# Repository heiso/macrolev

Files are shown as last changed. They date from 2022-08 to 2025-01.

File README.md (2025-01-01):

<div align="center" >
  Macrolev - Open Source Analog Keyboard
  <br>
  <br>
  <br>
  <div>
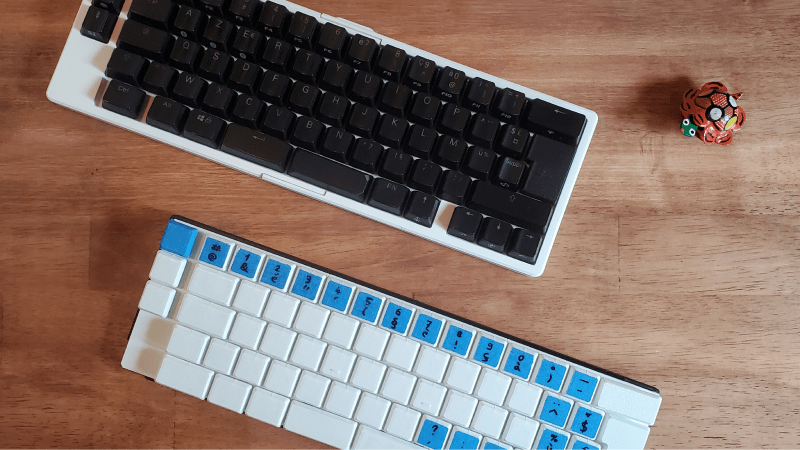
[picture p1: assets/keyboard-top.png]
keyboard - picture from above
    
  </div>
  <span>
    <a href="assets/keyboard-bot.png">bottom picture</a> - <a href="assets/pcb-bot.png">pcb picture</a> - 
  </span>
  <br>
  <br>
</div>

# Macrolev - Open Source Analog Keyboard

I use the two prototypes shown above as my daily drivers for both coding and gaming. They work well, and the current state of the web configurator is sufficient for seamlessly switching between coding and gaming modes. The current layout of my prototypes is Mac ISO azerty (FR).

## Features

- **Analog Input:** Each key detects varying levels of pressure thanks to Hall Effect technology, allowing for a more responsive and sensitive typing experience.
- **Rapid Trigger Support:** Enables keys to actuate without fully releasing, allowing for faster response times during intense usage (e.g., gaming or rapid typing).
- **Continuous Rapid Trigger:** For keys that require repeated pressing (e.g., in gaming), this feature allows automatic repeated key input with a single press.
- **Tap and Hold Functionality:** Each key can be assigned two functions. A tap function for quick presses and a hold function for longer presses. This is ideal for combining shortcuts or creating multi-functional keys, such as assigning the right Shift key to act as an arrow up when tapped.
- **Web-Based Configurator:** Allows customization of key sensitivity and rapid trigger settings, with future updates planned to enable key mapping and expanded functionality. (see [screenshot](assets/web-configurator-screenshot.png))

## Todos

This is still a work in progress, the firt revision is working flawlessly but it is not that configurable yet. Here is some of the things I'm working on right now

- [x] PCB Rev 2.0
- [ ] Explore other MCUs
  - [ ] esp32-s3 (in progress)
  - [ ] nRF52840
  - [ ] RP2354 ?
- [ ] Add Bluetooth
- [ ] Configure layout and key mapping from the web interface
- [ ] Improve performances

## Links

- [keyboard layout](http://www.keyboard-layout-editor.com/#/gists/9dc992fd631d9f29cc5bdf738b10b4e4)
- [Onshape - Case](https://cad.onshape.com/documents/2af2025c576c4f084cb26625/w/9564bb1d9dfbd4b4af4294c8/e/e2406b8294380372b9116245)
- [Onshape - Low profile MX keycaps](https://cad.onshape.com/documents/93ff700fd3fbb6e9cde6f6e3)
- [Rev 1.0 Schema](https://kicanvas.org/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)
- [Rev 1.0 Pcb](https://kicanvas.org/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)
- [Rev 2.0 Schema](https://kicanvas.org/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)
- [Rev 2.0 Pcb](https://kicanvas.org/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)
- [Rev 2.0 Schema (daughter board)](https://kicanvas.org/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)
- [Rev 2.0 Pcb (daughter board)](https://kicanvas.org/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)
- [Web Configurator](https://heiso.github.io/macrolev/)

## Misc

### References

- ~~[RP2040 Datasheet](https://datasheets.raspberrypi.com/rp2040/rp2040-datasheet.pdf)~~
- ~~[RP2040 Hardware Design](https://datasheets.raspberrypi.com/rp2040/hardware-design-with-rp2040.pdf)~~
- ~~[kb2040 doc](https://learn.adafruit.com/adafruit-kb2040/downloads)~~
- ~~[RPi Pico Debugger Shoe](https://github.com/ShawnHymel/rpi-pico-debugger-shoe)~~
- [Dilemma keyboard](https://github.com/Bastardkb/Dilemma)
- [0xB2 - splinky](https://github.com/plut0nium/0xB2)
- [Sub Reddit](https://www.reddit.com/r/PrintedCircuitBoard/search/?q=rp2040&restrict_sr=1&sr_nsfw=&include_over_18=1)
- [layout/design ref](https://geekhack.org/index.php?topic=103671.0)
- [cirque trackpad](https://www.cirque.com/glidepoint-circle-trackpads)
- [MagLev_Switch_MX](https://github.com/famichu/MagLev_Switch_MX)
- [Anatomy of a keyboard](https://matt3o.com/anatomy-of-a-keyboard/)
- [Switches/Stabs Kicad footprints from ebastler/marbastlib](https://github.com/ebastler/marbastlib)
- [Reddit Post about someone building a lekker switch based keyboard](https://www.reddit.com/r/PrintedCircuitBoard/comments/152kt63/review_request_analog_hall_effect_75_iso_keyboard/)
- [Riskable projects](https://github.com/riskable)
- [Fluxpad with lekker switches](https://github.com/sssata/fluxpad)
- [STM32F411CEU6 documentation](https://www.st.com/en/microcontrollers-microprocessors/stm32f411ce.html#documentation)
- [Wooting 60HE pcb](https://github.com/heiso/macrolev/tree/main/ref/Wooting-60HE)
- [Connecting to uncommon HID devices](https://developer.chrome.com/articles/hid)
- [HID Descriptor parser](https://eleccelerator.com/usbdescreqparser/)
- [peppapighs HE8 keyboard](https://github.com/peppapighs/HE8)
- [peppapighs libhmk library](https://github.com/peppapighs/libhmk)
- [nuphy configurator demo](https://drive.nuphy.io/?isDemoMode=true)
- [geonworks configurator demo](https://venom.how/)
- [wooting configurator demo](https://wootility.io/)

### Tooling

- [QMK keyboard test](https://config.qmk.fm/#/test)
- [Keyboard ghosting interactive demonstration](https://www.microsoft.com/applied-sciences/projects/anti-ghosting-demo)
- [Kicad lib marbastlib](https://github.com/ebastler/marbastlib)
- [Debug HardFault](https://interrupt.memfault.com/blog/cortex-m-hardfault-debug)
- [ai03 Plate Generator](https://kbplate.ai03.com/)
- [JLC2KiCad_lib](https://github.com/TousstNicolas/JLC2KiCad_lib)

Add footprints and symbols from jlcpcb with this cmd

```bash
JLC2KiCadLib <...LCSC refs> -dir JLCPCB -symbol_lib JLCPCB
```

### PCB reviews

- [Review request on PrintedCircuitBoard (Rev 1.0)](https://www.reddit.com/r/PrintedCircuitBoard/comments/17hjp88/review_request_analog_keyboard)
- [Second review request on PrintedCircuitBoard (Rev 1.0)](https://www.reddit.com/r/PrintedCircuitBoard/comments/17kqc2j/review_request_analog_keyboard_2/)
- [Third review request on PrintedCircuitBoard (Rev 2.0)](https://www.reddit.com/r/PrintedCircuitBoard/comments/1h432q5/review_request_open_source_analog_keyboard/)

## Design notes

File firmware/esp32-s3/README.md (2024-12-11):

## Configure the project

Install idf.py cmd [https://docs.espressif.com/projects/esp-idf/en/latest/esp32/get-started/index.html]

```bash
mkdir ~/esp
cd ~/esp
git clone git@github.com:espressif/esp-idf.git
cd esp-idf
git submodule update --init --recursive
./esp-idf/install.sh
```

Then in your project `. ~/esp/esp-idf/export.sh`

Before project configuration and build, make sure to set the correct chip target using `idf.py set-target TARGET` command.

## Erase the NVRAM

Before flash it to the board, it is recommended to erase NVRAM if user doesn't want to keep the previous examples or other projects stored info 
using `idf.py -p PORT erase-flash`

## Build and Flash

Build the project, flash it to the board, and start the monitor tool to view the serial output by running `idf.py -p PORT flash monitor`.

(To exit the serial monitor, type `Ctrl-T + Ctrl-X`)

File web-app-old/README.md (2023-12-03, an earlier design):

# UwU Stack &middot; 

## Install and first run

```bash
npm i
cp .env.tpl .env
npm run up
npm run reset-database
npm run log
```

Then go to http://localhost:3000

## DevEnv actions

Start

```bash
npm run up
```

Show logs

```bash
npm run log
```

Stop

```bash
npm run down
```

Restart

```bash
npm run restart
```

Truncate Database, Migrate and apply seeds

```bash
npm run reset-database
```

Run Lint

```bash
npm run lint
```

Run tests

```bash
npm run test
```

## TODO

- ✅ ...Done
- ⌛️ ...In Progress
- 🚨 ...Bug
- 🚧 ...Improvment

- full sqlite option
- redis/postgres option
- auth flow
- ui

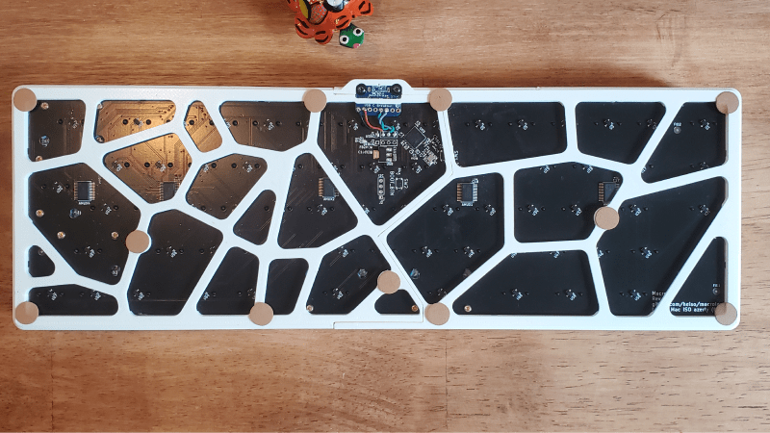
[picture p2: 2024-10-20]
assets/keyboard-bot.png

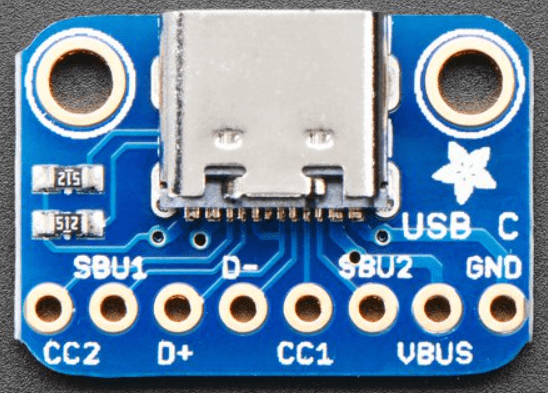
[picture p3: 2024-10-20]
assets/usbc.png

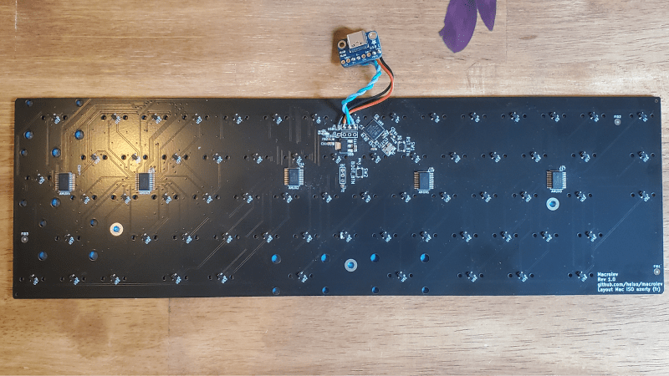
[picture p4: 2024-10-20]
assets/pcb-bot.png

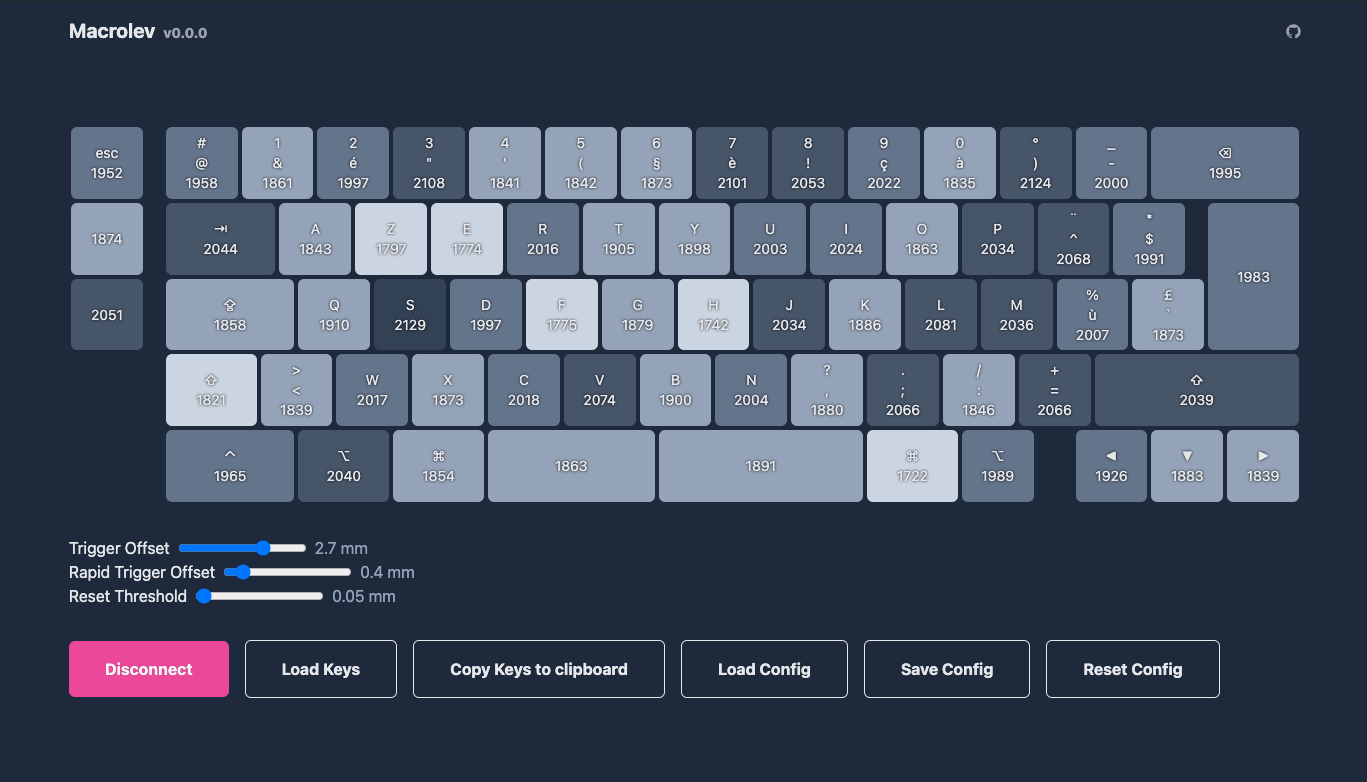
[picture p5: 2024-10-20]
assets/web-configurator-screenshot.png

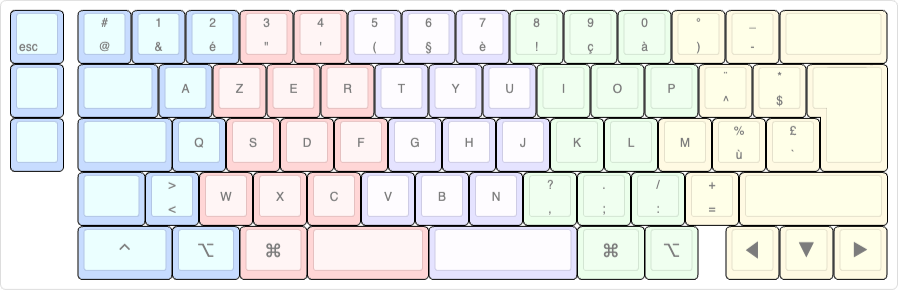
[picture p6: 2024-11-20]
assets/mac-iso-azerty-(fr).png

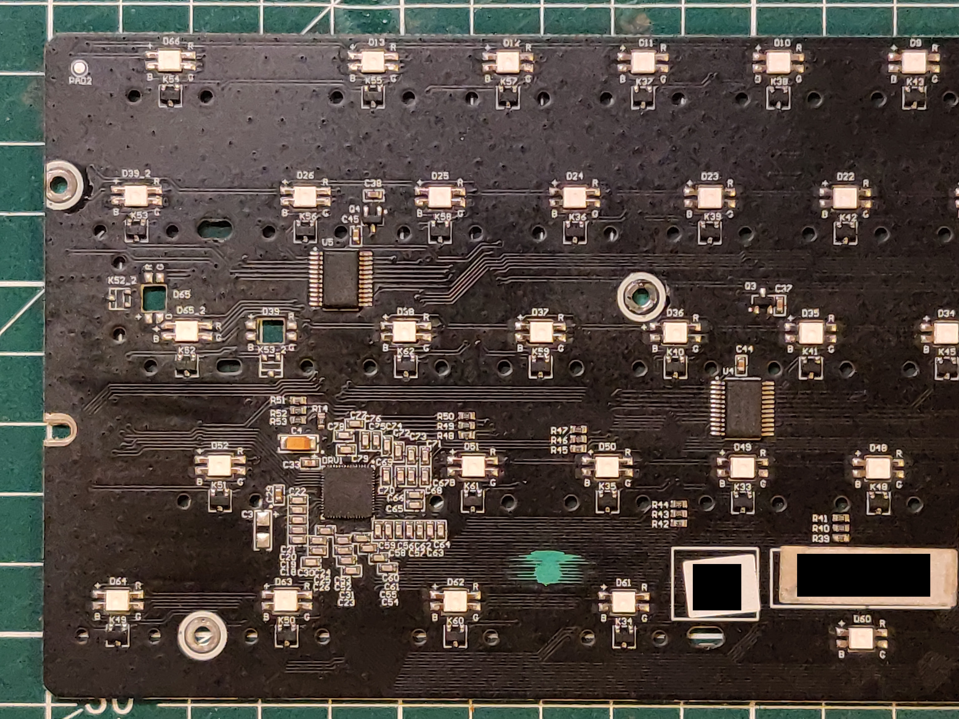
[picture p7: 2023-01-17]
ref/Wooting-60HE/W60HE-15.jpg

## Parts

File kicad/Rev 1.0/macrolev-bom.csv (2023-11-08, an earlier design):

Item | Qty | Reference(s) | Value | LibPart | Footprint | Datasheet | DNP | LCSC
1 | 5 | AMUX0, AMUX1, AMUX2, AMUX3, AMUX4 | CD74HC4067SM | 74xx:CD74HC4067SM | Package_SO:SSOP-24_5.3x8.2mm_P0.65mm | http://www.ti.com/lit/ds/symlink/cd74hc4067.pdf |  | C98457
2 | 1 | C1 | 10u | Device:C | Capacitor_SMD:C_0603_1608Metric_Pad1.08x0.95mm_HandSolder | ~ |  | C19702
3 | 10 | C2, C3, C4, C5, C9, C14, C15, C16, C17, C18 | 100n | Device:C | Capacitor_SMD:C_0402_1005Metric_Pad0.74x0.62mm_HandSolder | ~ |  | C1525
4 | 1 | C6 | 10n | Device:C | Capacitor_SMD:C_0402_1005Metric_Pad0.74x0.62mm_HandSolder | ~ |  | C15195
5 | 2 | C7, C8 | 1u | Device:C | Capacitor_SMD:C_0402_1005Metric_Pad0.74x0.62mm_HandSolder | ~ |  | C52923
6 | 2 | C10, C11 | 22u | Device:C | Capacitor_SMD:C_0805_2012Metric_Pad1.18x1.45mm_HandSolder | ~ |  | C45783
7 | 2 | C12, C13 | 20p | Device:C | Capacitor_SMD:C_0402_1005Metric_Pad0.74x0.62mm_HandSolder | ~ |  | C1554
8 | 1 | D1 | RED | Device:LED | LED_SMD:LED_0603_1608Metric_Pad1.05x0.95mm_HandSolder | ~ |  | C2286
9 | 2 | FB1, FB2 | 120R | Device:FerriteBead | Inductor_SMD:L_0603_1608Metric_Pad1.05x0.95mm_HandSolder | ~ |  | C76892
14 | 2 | R1, R2 | 1.2K | Device:R | Resistor_SMD:R_0402_1005Metric_Pad0.72x0.64mm_HandSolder | ~ |  | C25862
15 | 2 | R3, R4 | 10k | Device:R | Resistor_SMD:R_0402_1005Metric_Pad0.72x0.64mm_HandSolder | ~ |  | C25744
16 | 1 | R5 | 5.1k | Device:R | Resistor_SMD:R_0402_1005Metric_Pad0.72x0.64mm_HandSolder | ~ |  | C25905
17 | 1 | SW1 | RST_BTN | Switch:SW_Push_Dual | switch:SKRPACE010 | ~ |  | C139797
18 | 1 | SW2 | BOOT_BTN | Switch:SW_Push_Dual | switch:SKRPACE010 | ~ |  | C139797
19 | 67 | U1, U2, U3, U4, U5, U6, U7, U8, U9, U10, U11, U12, U13, U14, U15, U16, U17, U18, U19, U20, U21, U22, U23, U24, U25, U26, U27, U28, U29, U30, U31, U32, U33, U34, U35, U36, U37, U38, U39, U40, U41, U42, U43, U44, U45, U46, U47, U48, U49, U50, U51, U52, U53, U54, U55, U56, U57, U58, U59, U60, U61, U62, U63, U64, U65, U66, U67 | A1101ELHL | Sensor_Magnetic:A1101ELHL | Package_TO_SOT_SMD:SOT-23 | https://www.allegromicro.com/-/media/files/datasheets/a110x-datasheet.ashx |  | C266230
20 | 1 | U68 | AMS1117-3.3 | Regulator_Linear:AMS1117-3.3 | Package_TO_SOT_SMD:SOT-223-3_TabPin2 | http://www.advanced-monolithic.com/pdf/ds1117.pdf |  | C6186
21 | 1 | U69 | STM32F411CEU6 | MCU_ST_STM32F4:STM32F411CEUx | Package_DFN_QFN:QFN-48-1EP_7x7mm_P0.5mm_EP5.6x5.6mm | https://www.st.com/resource/en/datasheet/stm32f411ce.pdf |  | C60420
22 | 1 | Y1 | 25MHz/20ppm/15pF | Device:Crystal_GND24 | Crystal:Crystal_SMD_3225-4Pin_3.2x2.5mm_HandSoldering | ~ |  | C387396

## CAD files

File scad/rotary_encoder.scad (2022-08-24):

use <blank.scad>
use <utils.scad>
// 2-4mm of travel is traditional for mechanical key switches
TOTAL_TRAVEL = 4; // [1:0.1:20]

/* [Advanced Stuff] */

BODY_LENGTH = 14.2;
BODY_WIDTH = 14.2;
BODY_HEIGHT = 7;
BODY_CORNER_RADIUS = 0.5;
WALL_THICKNESS = 0.8;
COVER_THICKNESS = 0.5; // [0:0.1:1.5]
COVER_OVERHANG = 0.6;  // [0:0.1:1.5]

CLIP_BRIDGE_THICKNESS = 0.3;
SWITCH_PLATE_THICKNESS = 1.5;
SWITCH_PLATE_TOLERANCE = 0.2;

BODY_TAPER = 1.05;

ROTARY_ENCODER_BODY_HEIGHT = 6.6;
INTERNAL_HEIGHT = 3;

// OpenSCAD's rendering resolution (64 worked well for me but feel free to go higher if you're patient--unlike me)
$fn = 64;

difference()
{
    union()
    {
        switch_body(BODY_LENGTH, BODY_WIDTH, TOTAL_TRAVEL, cover_overhang = COVER_OVERHANG, taper = BODY_TAPER,
                    wall_thickness = WALL_THICKNESS, cover_thickness = COVER_THICKNESS,
                    plate_thickness = SWITCH_PLATE_THICKNESS, plate_tolerance = SWITCH_PLATE_TOLERANCE,
                    corner_radius = BODY_CORNER_RADIUS, bridge_thickness = CLIP_BRIDGE_THICKNESS, height = BODY_HEIGHT);

        translate([ -6.5, -5, 0 ])
        {
            cube([ 13, 10, INTERNAL_HEIGHT ]);
        }
    }

    translate([ 5, -1, INTERNAL_HEIGHT - 1.4 ])
    {
        cube([ 1.3, 2, 1.5 ]);
    }

    cylinder(BODY_HEIGHT, r = 7 / 2);
}

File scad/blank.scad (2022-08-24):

use <utils.scad>
// 2-4mm of travel is traditional for mechanical key switches
TOTAL_TRAVEL = 4; // [1:0.1:20]

/* [Advanced Stuff] */

BODY_LENGTH = 14.2;
BODY_WIDTH = 14.2;
BODY_HEIGHT = 7;
BODY_CORNER_RADIUS = 0.5;
WALL_THICKNESS = 1.35;
COVER_THICKNESS = 0.5; // [0:0.1:1.5]
COVER_OVERHANG = 0.6;  // [0:0.1:1.5]

CLIP_BRIDGE_THICKNESS = 0.3;
SWITCH_PLATE_THICKNESS = 1.5;
SWITCH_PLATE_TOLERANCE = 0.2;

BODY_TAPER = 1.1;

// OpenSCAD's rendering resolution (64 worked well for me but feel free to go higher if you're patient--unlike me)
$fn = 64;

module switch_body(length, width, travel, cover_overhang = 1, taper = 1.1, wall_thickness = 1.4, cover_thickness = 0.6,
                   plate_thickness = 1.5, plate_tolerance = 0.2, corner_radius = 0.5, bridge_thickness = 0.3,
                   height = 0)
{
    body_height = height;       // For clarity in the code
    snap_clip_protrusion = 0.2; // How much the little snap lip things stick out from the body (it gets rotate 45° so
                                // it's a little less, actually)
    snap_clip_thickness = 0.85; // How thick the clips are

    clip_width = width / 6;
    clip_side_hole_width = 0.35; // How wide the cutouts are beside each clip
    note(str("UNDER_PLATE_HEIGHT: ", body_height - cover_thickness));
    difference()
    {
        union()
        {
            // Generate the part of the body that overhangs the hole on the plate
            translate([ 0, 0, cover_thickness / 2 ]) hull()
            { // This is tapered a bit to make removing the switch easier
                squarish_rpoly(
                    xy =
                        [ length + cover_overhang - plate_tolerance / 2, width + cover_overhang - plate_tolerance / 2 ],
                    h = cover_thickness, r = corner_radius, center = true);
                translate([ 0, 0, -cover_thickness / 4 ])
                    squarish_rpoly(xy =
                                       [
                                           length + cover_overhang * 2 - plate_tolerance / 2,
                                           width + cover_overhang * 2 - plate_tolerance / 2
                                       ],
                                   h = cover_thickness / 2, r = corner_radius, center = true);
            }
            // Generate the main body of the switch
            difference()
            {
                translate([ 0, 0, cover_thickness ]) hull()
                {
                    translate([ 0, 0, plate_thickness / 2 ])
                        squarish_rpoly(xy = [ length - plate_tolerance / 2, width - plate_tolerance / 2 ],
                                       h = plate_thickness, r = corner_radius, center = true);
                    translate([ 0, 0, body_height - cover_thickness ])
                        squarish_rpoly(xy = [ length / taper, width / taper ],
                                       h = cover_thickness / 2, // Close enough
                                       r = corner_radius, center = true);
                }

                difference()
                {
                    // NOTE: Because of the body taper we need to increase the wall thickness here slightly so that it
                    // prints well (don't want the slicer cutting off the corners).  That's why we have this "interior
                    // bulge" thing...
                    translate([ 0, 0, -cover_thickness / 2 ]) hull()
                    {
                        // NOTE: The interior taper here is to give the wall-to-cover attachment a stronger bond
                        // (otherwise the top of the switch can break right off leaving you with a top and a hollow
                        // cube)
                        squarish_rpoly(xy = [ length - wall_thickness * 3.75, width - wall_thickness * 3.75 ],
                                       h = cover_thickness / 2, r = corner_radius / 1.5, center = true);
                        translate([ 0, 0, body_height / 4 ])
                            squarish_rpoly(xy = [ length - wall_thickness * 2, width - wall_thickness * 2 ],
                                           h = cover_thickness / 2, r = corner_radius / 1.5, center = true);
                        translate([ 0, 0, cover_thickness + height + wall_thickness / 2 ]) squarish_rpoly(
                            xy = [ length / taper - wall_thickness * 1.25, width / taper - wall_thickness * 1.25 ],
                            h = cover_thickness, r = corner_radius / 1.5, center = true);
                    }
                }
                // Create a gap underneath the clips so they can move freely
                gap_size = plate_thickness / 2;
                translate([ clip_width, 0, cover_thickness / 2 + gap_size / 2 ])
                    cube([ clip_width + clip_side_hole_width * 2, width * 2, gap_size ], center = true);
                translate([ -clip_width, width / 2, cover_thickness / 2 + gap_size / 2 ])
                    cube([ clip_width + clip_side_hole_width * 2, width / 2, gap_size ], center = true);
                // Cutout holes beside the clips so they can bend (slightly) easier when inserting
                translate([
                    clip_width + clip_width / 2 + clip_side_hole_width / 2, 0,
                    cover_thickness / 2 + travel / 2 + plate_thickness / 2 +
                    bridge_thickness
                ]) cube([ clip_side_hole_width, width * 2, travel ], center = true);
                translate([
                    clip_width - clip_width / 2 - clip_side_hole_width / 2, 0,
                    cover_thickness / 2 + travel / 2 + plate_thickness / 2 +
                    bridge_thickness
                ]) cube([ clip_side_hole_width, width * 2, travel ], center = true);
                translate([
                    -clip_width - clip_width / 2 - clip_side_hole_width / 2,
                    length / 2 + snap_clip_protrusion - cover_overhang / 1.15,
                    cover_thickness / 2 + travel / 2 + plate_thickness / 2 +
                    bridge_thickness
                ]) cube([ clip_side_hole_width, width / 2, travel ], center = true);
                translate([
                    -clip_width + clip_width / 2 + clip_side_hole_width / 2,
                    length / 2 + snap_clip_protrusion - cover_overhang / 1.15,
                    cover_thickness / 2 + travel / 2 + plate_thickness / 2 +
                    bridge_thickness
                ]) cube([ clip_side_hole_width, width / 2, travel ], center = true);
                // Carve out a bit of the bridge that supports the clips so it can break away easier upon first
                // insertion of the switch into the plate
                translate([ // Back side left
                    -clip_width,
                    length/2-wall_thickness/1.55,
                    cover_thickness/2+plate_thickness/2+bridge_thickness/2])
                        cube([
                            clip_width+clip_side_hole_width*2,
                            wall_thickness/3.5,
                            bridge_thickness+0.01], center=true);
                translate([ // Back side right
                    clip_width,
                    length/2-wall_thickness/1.55,
                    cover_thickness/2+plate_thickness/2+bridge_thickness/2])
                        cube([
                            clip_width+clip_side_hole_width*2,
                            wall_thickness/3.5,
                            bridge_thickness+0.01], center=true);
                translate([ // Front side right
                    clip_width,
                    -length/2+wall_thickness/1.55,
                    cover_thickness/2+plate_thickness/2+bridge_thickness/2])
                        cube([
                            clip_width+clip_side_hole_width*2,
                            wall_thickness/3.5,
                            bridge_thickness+0.01], center=true);
            }
        }
    }
    // Add little snap/clip nubs so the switch can "snap" into place (and stay there)
    if (cover_overhang)
    { // Don't need the clips if doing flush mount
        translate([
            clip_width, length / 2 + snap_clip_protrusion - cover_overhang / 1.15,
            cover_thickness + snap_clip_thickness / 1.25 +
            plate_thickness
        ]) rotate([ -60, 0, 0 ]) cube([ clip_width, snap_clip_thickness * 2, snap_clip_thickness ], center = true);
        translate([
            -clip_width, length / 2 + snap_clip_protrusion - cover_overhang / 1.15,
            cover_thickness + snap_clip_thickness / 1.25 +
            plate_thickness
        ]) rotate([ -60, 0, 0 ]) cube([ clip_width, snap_clip_thickness * 2, snap_clip_thickness ], center = true);
        translate([
            clip_width, -length / 2 - snap_clip_protrusion + cover_overhang / 1.15,
            cover_thickness + snap_clip_thickness / 1.25 +
            plate_thickness
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

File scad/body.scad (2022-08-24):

// Modules related to the main body of the switch

use <utils.scad>

// Constants
CHERRY_CROSS_LENGTH = 4; // Length of the - and the | in the +

// TODO: Document all these args
// The main housing of the switch that the sheath slides into
module switch_body(length, width, travel, taper = 1.1, wall_thickness = 1.4, sheath_wall_thickness = 1.2,
                   sheath_length = 3, cover_overhang = 1, cover_thickness = 0.6, plate_thickness = 1.5,
                   plate_tolerance = 0.2, stem_diameter = 4.1, sheath_tolerance = 0.2, lip_height = 1,
                   top_magnet_height = 2, top_magnet_diameter = 6, top_magnet_cover_thickness = -0.5,
                   magnet_height = 1.5, magnet_wall_thickness = 0.5, magnet_tolerance = 0.15, magnet_void = 0.0,
                   sheath_end_stop_thickness = 0.8, corner_radius = 0.5, droop_extra = 0.2, sheath_clip_width = 1.5,
                   top_clip_hole_length = 2.15, top_clip_hole_width = 3.15, stem_tolerance = 0.15,
                   bridge_thickness = 0.3, sheath_snug_magnet = true, sheath_inside_body = false, height = 0)
{
    total_travel = travel + top_magnet_height; // Actual total travel
    // How far into the body the stem shroud goes (so we can calculate depth)
    sheath_depth = (cover_thickness + sheath_length + total_travel - top_magnet_cover_thickness + magnet_height +
                    magnet_wall_thickness * 2 + magnet_tolerance + magnet_void +
                    sheath_end_stop_thickness); // NOTE: Does not include the lip_height on purpose
    // adjusted_magnet_wall_thickness = sheath_inside_body ? 0 : magnet_wall_thickness;
    body_height = height ? height : sheath_depth; // For clarity in the code
                                                  //    echo(body_height=body_height);
    // NOTE: These two sheath variables need to match how they're handled in the actual sheath:
    sheath_width = stem_diameter + sheath_wall_thickness * 2;
    sheath_height = stem_diameter + sheath_wall_thickness * 2;
    snap_clip_protrusion = 0.2; // How much the little snap lip things stick out from the body (it gets rotate 45° so
                                // it's a little less, actually)
    snap_clip_thickness = 0.85; // How thick the clips are
    pin_diameter = 1.875;       // Need to match the pin diameter used by the stabilizer clips
    clip_width = width / 6;
    clip_side_hole_width = 0.35; // How wide the cutouts are beside each clip
    note(str("UNDER_PLATE_HEIGHT: ", body_height - cover_thickness));
    difference()
    {
        union()
        {
            // Generate the part of the body that overhangs the hole on the plate
            translate([ 0, 0, cover_thickness / 2 ]) hull()
            { // This is tapered a bit to make removing the switch easier
                squarish_rpoly(
                    xy =
                        [ length + cover_overhang - plate_tolerance / 2, width + cover_overhang - plate_tolerance / 2 ],
                    h = cover_thickness, r = corner_radius, center = true);
                translate([ 0, 0, -cover_thickness / 4 ])
                    squarish_rpoly(xy =
                                       [
                                           length + cover_overhang * 2 - plate_tolerance / 2,
                                           width + cover_overhang * 2 - plate_tolerance / 2
                                       ],
                                   h = cover_thickness / 2, r = corner_radius, center = true);
            }
            // Generate the main body of the switch
            difference()
            {
                translate([ 0, 0, cover_thickness ]) hull()
                {
                    translate([ 0, 0, plate_thickness / 2 ])
                        squarish_rpoly(xy = [ length - plate_tolerance / 2, width - plate_tolerance / 2 ],
                                       h = plate_thickness, r = corner_radius, center = true);
                    translate([ 0, 0, body_height - cover_thickness ])
                        squarish_rpoly(xy = [ length / taper, width / taper ],
                                       h = cover_thickness / 2, // Close enough
                                       r = corner_radius, center = true);
                }
                // Cut out the corner so we don't have to worry about a large stem/magnet scraping the sides
                //                adjusted_magnet_wall_thickness = sheath_inside_body ? 0 : magnet_wall_thickness;
                translate([
                    -length / 2.85, -width / 2.85,
                    body_height / 2 + top_magnet_height + magnet_wall_thickness + droop_extra -
                        top_magnet_cover_thickness +
                    sheath_length
                ]) cube([ length / 2, width / 2, body_height ], center = true);
                difference()
                {
                    // NOTE: Because of the body taper we need to increase the wall thickness here slightly so that it
                    // prints well (don't want the slicer cutting off the corners).  That's why we have this "interior
                    // bulge" thing...
                    translate([ 0, 0, -cover_thickness / 2 ]) hull()
                    {
                        // NOTE: The interior taper here is to give the wall-to-cover attachment a stronger bond
                        // (otherwise the top of the switch can break right off leaving you with a top and a hollow
                        // cube)
                        squarish_rpoly(xy = [ length - wall_thickness * 3.75, width - wall_thickness * 3.75 ],
                                       h = cover_thickness / 2, r = corner_radius / 1.5, center = true);
                        translate([ 0, 0, body_height / 4 ])
                            squarish_rpoly(xy = [ length - wall_thickness * 2, width - wall_thickness * 2 ],
                                           h = cover_thickness / 2, r = corner_radius / 1.5, center = true);
                        translate([ 0, 0, cover_thickness + sheath_depth + magnet_height + wall_thickness / 2 ])
                            squarish_rpoly(
                                xy = [ length / taper - wall_thickness * 1.25, width / taper - wall_thickness * 1.25 ],
                                h = cover_thickness, r = corner_radius / 1.5, center = true);
                    }
                    // This gives the magnet a bit of a "seat" so it doesn't fall through:
                    translate([
                        -length / 2 - top_magnet_diameter / 2.2, -width / 2 - top_magnet_diameter / 2.2,
                        -magnet_wall_thickness / 2 + top_magnet_height + magnet_wall_thickness + droop_extra -
                            top_magnet_cover_thickness +
                        sheath_length
                    ]) rotate([ 0, 0, 45 ])
                        cube(
                            [
                                length,
                                width,
                                magnet_wall_thickness,
                            ],
                            center = true);
                }
                // Add a little hole that ensures the bridging goes right
                translate([
                    -length / 2 + top_magnet_diameter / 1.65, -width / 2 + top_magnet_diameter / 1.65,
                    -(magnet_wall_thickness + droop_extra) / 2 + top_magnet_height + magnet_wall_thickness +
                        droop_extra - top_magnet_cover_thickness +
                    sheath_length
                ]) difference()
                {
                    cube([ 2, 2, magnet_wall_thickness + droop_extra + 0.01 ], center = true);
                    translate([ 0.65, 0.65, 0 ]) rotate([ 0, 0, 45 ])
                        cube([ 2, 3, magnet_wall_thickness * 10 ], center = true);
                }
                // TODO: Make these hard-coded numbers like -4.7 take the size of the body into account...
                // Cut out the sides near where the stem presses against the magnet so it doesn't get caught on the
                // sides
                translate([ -4.7, -1, top_magnet_height ]) cube([ 2, 1.6, top_magnet_height * 2 ], center = true);
                translate([ -1, -4.7, top_magnet_height ]) cube([ 1.6, 2, top_magnet_height * 2 ], center = true);
                if (cover_overhang)
                {
                    // Create a gap underneath the clips so they can move freely
                    gap_size = plate_thickness / 2;
                    translate([ clip_width, 0, cover_thickness / 2 + gap_size / 2 ])
                        cube([ clip_width + clip_side_hole_width * 2, width * 2, gap_size ], center = true);
                    translate([ -clip_width, width / 2, cover_thickness / 2 + gap_size / 2 ])
                        cube([ clip_width + clip_side_hole_width * 2, width / 2, gap_size ], center = true);
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

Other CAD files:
scad/parametrics-designs/parts/rotary_encoder.scad
kle-to-scad/src/utils.scad
scad/knob.scad
scad/levitator.scad
scad/parametrics-designs/body/body.scad
scad/parametrics-designs/parts/filler.scad
scad/parametrics-designs/parts/knob.scad
scad/parametrics-designs/parts/void_switch/body.scad
scad/parametrics-designs/parts/void_switch/levitator.scad
scad/parametrics-designs/parts/void_switch/sheath.scad
scad/parametrics-designs/parts/void_switch/stabilizer.scad
scad/parametrics-designs/parts/void_switch/stem.scad
scad/parametrics-designs/parts/void_switch/void_switch.scad
scad/parametrics-designs/utils.scad
scad/sheath.scad
scad/stabilizer.scad
scad/void_switch.scad

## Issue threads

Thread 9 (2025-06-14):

Source code documentation

hung9988, 2025-06-14:
Hi, i know this is not a very appropriate place to ask but would you by any chance intending on writing a documentation explaining the source code ?
I am a college student trying to learn about embedded system and very new to programming with STM32 MCU and it would be a great help if there is a documentation that i can read and understand reason behind your code.
It is totally ok if you dont have the time for it and if so can i ask you a few question in this thread here?

Thank you very much!

heiso, 2025-06-16:
> Hi, i know this is not a very appropriate place to ask but would you by any chance intending on writing a documentation explaining the source code ?

I think it is, thanks for asking.

To be fair i'm not having a lot of time to work on this project with my full time job. I'd love to help but i think documenting the code itself is not something on top of my priorities. First, i'd like to finish the "new" firmware for esp32.

I created a discord here for the project https://discord.gg/4CY4WrrKN4 hope on. I'm not promising you i'll be able to help you but if i have the time and can, i'll do gladly

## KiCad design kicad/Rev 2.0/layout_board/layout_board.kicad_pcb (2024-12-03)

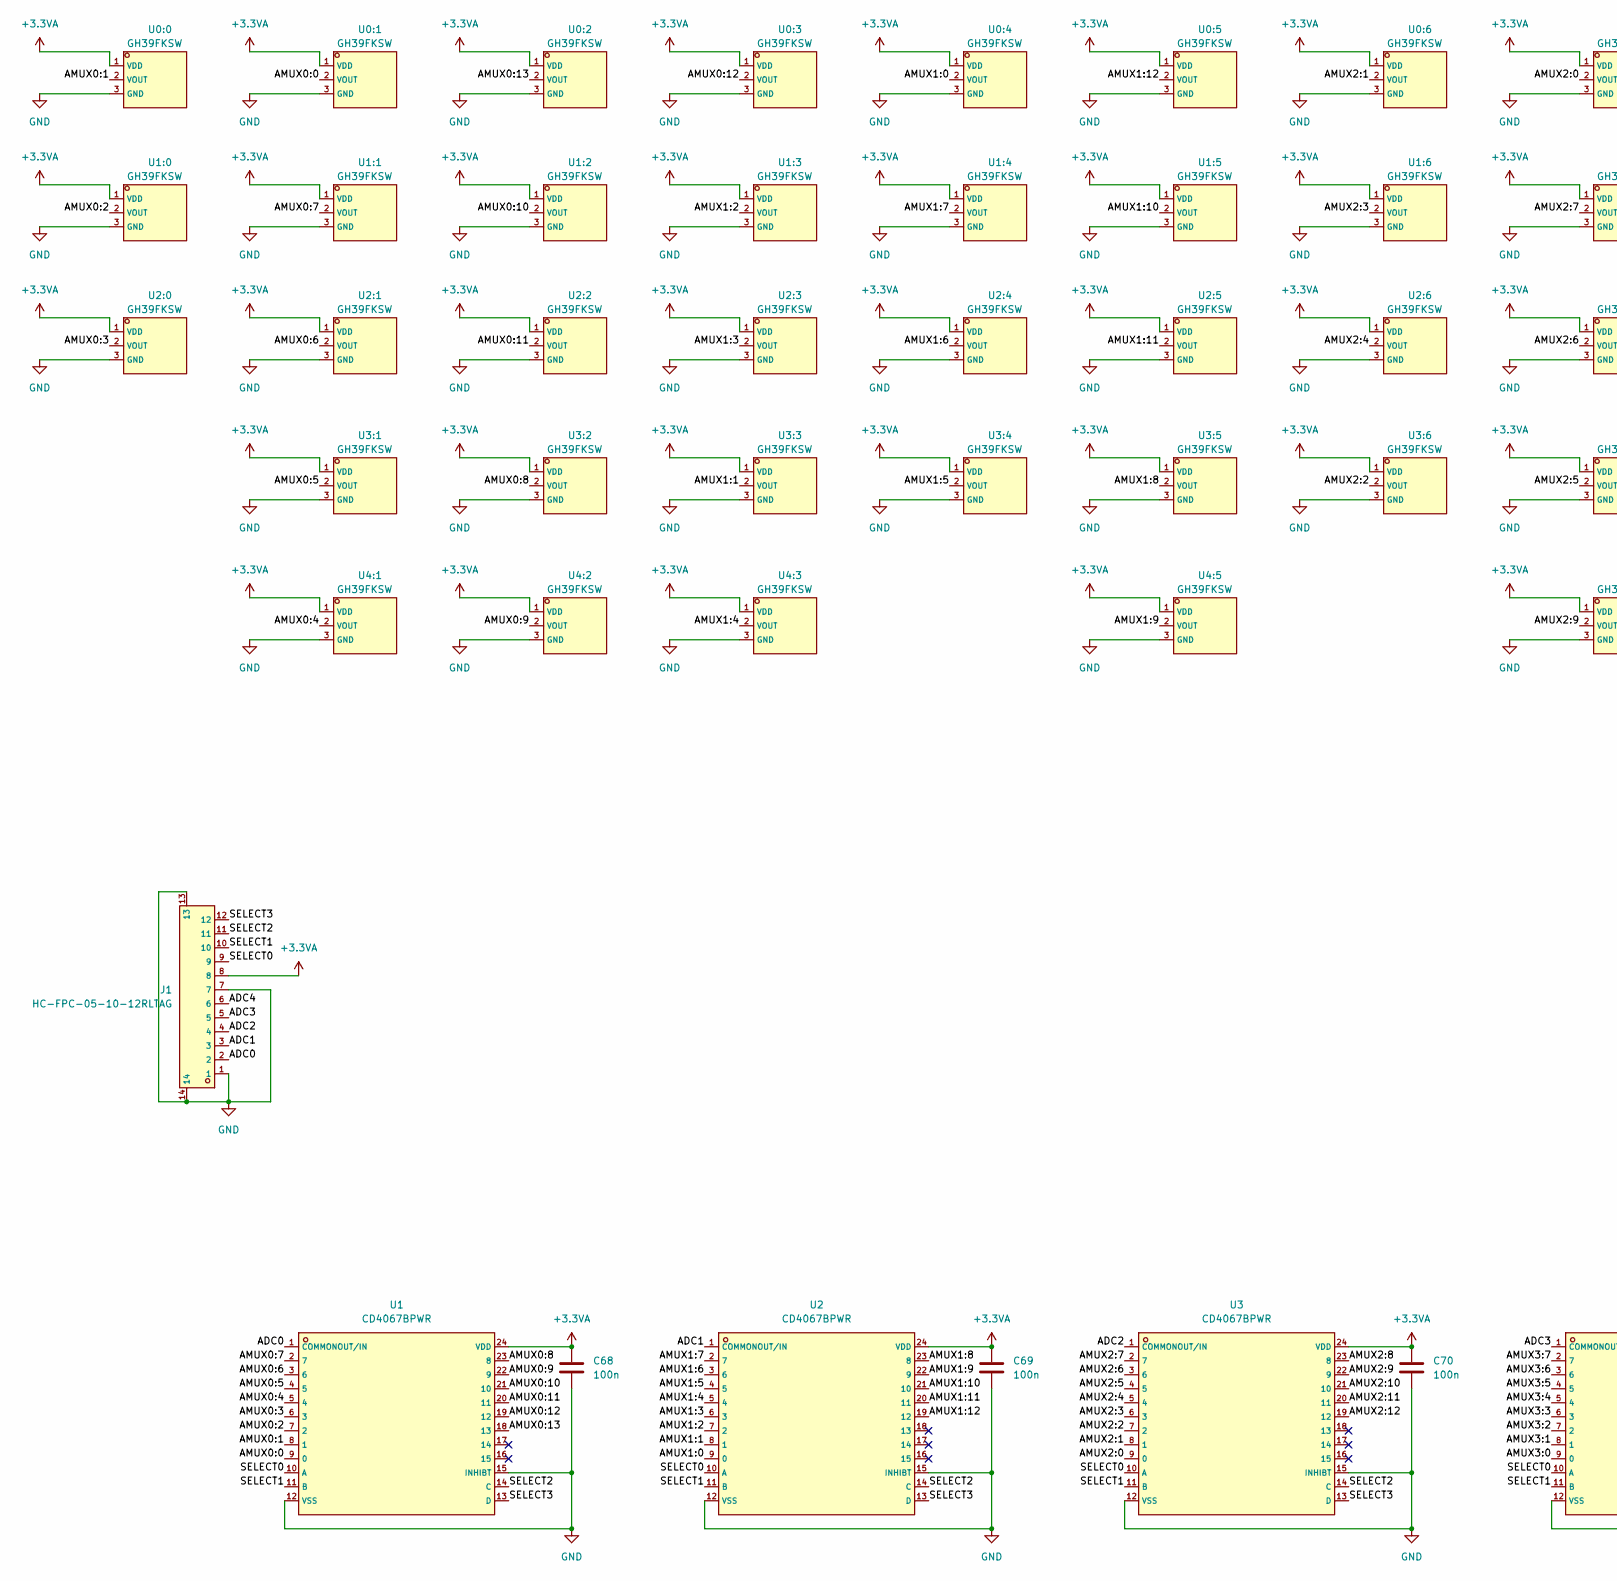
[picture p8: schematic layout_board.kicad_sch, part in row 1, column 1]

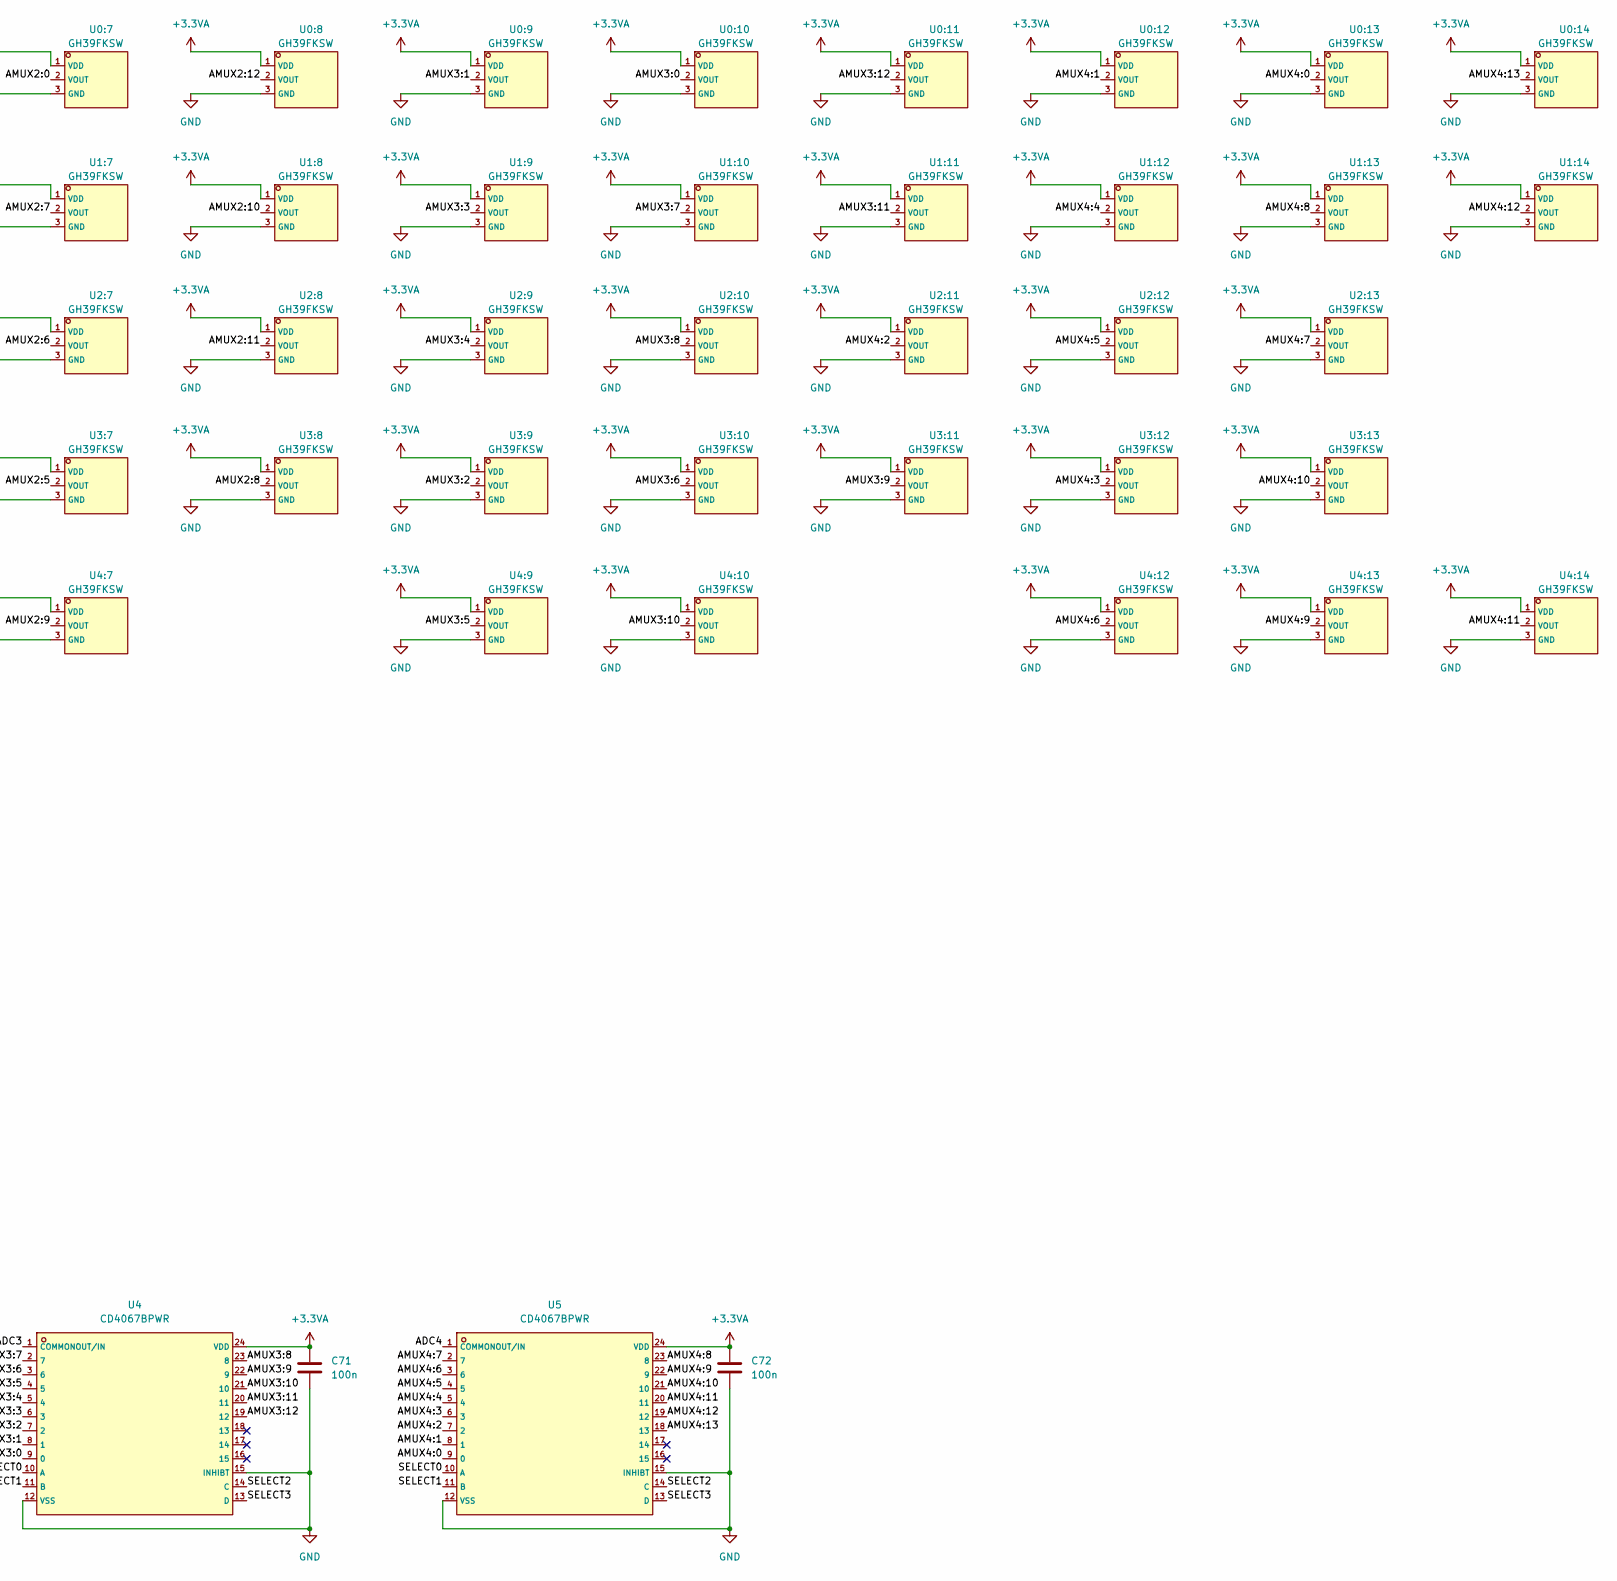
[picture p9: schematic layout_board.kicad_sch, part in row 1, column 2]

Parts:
C68, C69, C70, C71, C72: 100n; C_0402_1005Metric_Pad0.74x0.62mm_HandSolder; LCSC C1525
J1: HC-FPC-05-10-12RLTAG; FPC-SMD_12P-P0.50_HCTL_HC-FPC-05-10-12RLTAG; LCSC C5213732
U0:0, U0:1, U0:2, U0:3, U0:4, U0:5, U0:6, U0:7, U0:8, U0:9, U0:10, U0:11, U0:12, U0:13, U0:14, U1:0, U1:1, U1:2, U1:3, U1:4, U1:5, U1:6, U1:7, U1:8, U1:9, U1:10, U1:11, U1:12, U1:13, U1:14, U2:0, U2:1, U2:2, U2:3, U2:4, U2:5, U2:6, U2:7, U2:8, U2:9, U2:10, U2:11, U2:12, U2:13, U3:1, U3:2, U3:3, U3:4, U3:5, U3:6, U3:7, U3:8, U3:9, U3:10, U3:11, U3:12, U3:13, U4:1, U4:2, U4:3, U4:5, U4:7, U4:9, U4:10, U4:12, U4:13, U4:14: GH39FKSW; SOT-23; LCSC C266230
U1, U2, U3, U4, U5: CD4067BPWR; SSOP-24_5.3x8.2mm_P0.65mm; LCSC C2861251

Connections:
+3.3VA: C68.1, C69.1, C70.1, C71.1, C72.1, J1.8, U0:0.1 (VDD), U0:1.1 (VDD), U0:2.1 (VDD), U0:3.1 (VDD), U0:4.1 (VDD), U0:5.1 (VDD), U0:6.1 (VDD), U0:7.1 (VDD), U0:8.1 (VDD), U0:9.1 (VDD), U0:10.1 (VDD), U0:11.1 (VDD), U0:12.1 (VDD), U0:13.1 (VDD), U0:14.1 (VDD), U1.24 (VDD), U1:0.1 (VDD), U1:1.1 (VDD), U1:2.1 (VDD), U1:3.1 (VDD), U1:4.1 (VDD), U1:5.1 (VDD), U1:6.1 (VDD), U1:7.1 (VDD), U1:8.1 (VDD), U1:9.1 (VDD), U1:10.1 (VDD), U1:11.1 (VDD), U1:12.1 (VDD), U1:13.1 (VDD), U1:14.1 (VDD), U2.24 (VDD), U2:0.1 (VDD), U2:1.1 (VDD), U2:2.1 (VDD), U2:3.1 (VDD), U2:4.1 (VDD), U2:5.1 (VDD), U2:6.1 (VDD), U2:7.1 (VDD), U2:8.1 (VDD), U2:9.1 (VDD), U2:10.1 (VDD), U2:11.1 (VDD), U2:12.1 (VDD), U2:13.1 (VDD), U3.24 (VDD), U3:1.1 (VDD), U3:2.1 (VDD), U3:3.1 (VDD), U3:4.1 (VDD), U3:5.1 (VDD), U3:6.1 (VDD), U3:7.1 (VDD), U3:8.1 (VDD), U3:9.1 (VDD), U3:10.1 (VDD), U3:11.1 (VDD), U3:12.1 (VDD), U3:13.1 (VDD), U4.24 (VDD), U4:1.1 (VDD), U4:2.1 (VDD), U4:3.1 (VDD), U4:5.1 (VDD), U4:7.1 (VDD), U4:9.1 (VDD), U4:10.1 (VDD), U4:12.1 (VDD), U4:13.1 (VDD), U4:14.1 (VDD), U5.24 (VDD)
/ADC0: J1.2, U1.1 (COMMONOUT/IN)
/ADC1: J1.3, U2.1 (COMMONOUT/IN)
/ADC2: J1.4, U3.1 (COMMONOUT/IN)
/ADC3: J1.5, U4.1 (COMMONOUT/IN)
/ADC4: J1.6, U5.1 (COMMONOUT/IN)
/AMUX0:0: U0:1.2 (VOUT), U1.9 (0)
/AMUX0:1: U0:0.2 (VOUT), U1.8 (1)
/AMUX0:2: U1.7 (2), U1:0.2 (VOUT)
/AMUX0:3: U1.6 (3), U2:0.2 (VOUT)
/AMUX0:4: U1.5 (4), U4:1.2 (VOUT)
/AMUX0:5: U1.4 (5), U3:1.2 (VOUT)
/AMUX0:6: U1.3 (6), U2:1.2 (VOUT)
/AMUX0:7: U1.2 (7), U1:1.2 (VOUT)
/AMUX0:8: U1.23 (8), U3:2.2 (VOUT)
/AMUX0:9: U1.22 (9), U4:2.2 (VOUT)
/AMUX0:10: U1.21 (10), U1:2.2 (VOUT)
/AMUX0:11: U1.20 (11), U2:2.2 (VOUT)
/AMUX0:12: U0:3.2 (VOUT), U1.19 (12)
/AMUX0:13: U0:2.2 (VOUT), U1.18 (13)
/AMUX1:0: U0:4.2 (VOUT), U2.9 (0)
/AMUX1:1: U2.8 (1), U3:3.2 (VOUT)
/AMUX1:2: U1:3.2 (VOUT), U2.7 (2)
/AMUX1:3: U2.6 (3), U2:3.2 (VOUT)
/AMUX1:4: U2.5 (4), U4:3.2 (VOUT)
/AMUX1:5: U2.4 (5), U3:4.2 (VOUT)
/AMUX1:6: U2.3 (6), U2:4.2 (VOUT)
/AMUX1:7: U1:4.2 (VOUT), U2.2 (7)
/AMUX1:8: U2.23 (8), U3:5.2 (VOUT)
/AMUX1:9: U2.22 (9), U4:5.2 (VOUT)
/AMUX1:10: U1:5.2 (VOUT), U2.21 (10)
/AMUX1:11: U2.20 (11), U2:5.2 (VOUT)
/AMUX1:12: U0:5.2 (VOUT), U2.19 (12)
/AMUX2:0: U0:7.2 (VOUT), U3.9 (0)
/AMUX2:1: U0:6.2 (VOUT), U3.8 (1)
/AMUX2:2: U3.7 (2), U3:6.2 (VOUT)
/AMUX2:3: U1:6.2 (VOUT), U3.6 (3)
/AMUX2:4: U2:6.2 (VOUT), U3.5 (4)
/AMUX2:5: U3.4 (5), U3:7.2 (VOUT)
/AMUX2:6: U2:7.2 (VOUT), U3.3 (6)
/AMUX2:7: U1:7.2 (VOUT), U3.2 (7)
/AMUX2:8: U3.23 (8), U3:8.2 (VOUT)
/AMUX2:9: U3.22 (9), U4:7.2 (VOUT)
/AMUX2:10: U1:8.2 (VOUT), U3.21 (10)
/AMUX2:11: U2:8.2 (VOUT), U3.20 (11)
/AMUX2:12: U0:8.2 (VOUT), U3.19 (12)
/AMUX3:0: U0:10.2 (VOUT), U4.9 (0)
/AMUX3:1: U0:9.2 (VOUT), U4.8 (1)
/AMUX3:2: U3:9.2 (VOUT), U4.7 (2)
/AMUX3:3: U1:9.2 (VOUT), U4.6 (3)
/AMUX3:4: U2:9.2 (VOUT), U4.5 (4)
/AMUX3:5: U4.4 (5), U4:9.2 (VOUT)
/AMUX3:6: U3:10.2 (VOUT), U4.3 (6)
/AMUX3:7: U1:10.2 (VOUT), U4.2 (7)
/AMUX3:8: U2:10.2 (VOUT), U4.23 (8)
/AMUX3:9: U3:11.2 (VOUT), U4.22 (9)
/AMUX3:10: U4.21 (10), U4:10.2 (VOUT)
/AMUX3:11: U1:11.2 (VOUT), U4.20 (11)
/AMUX3:12: U0:11.2 (VOUT), U4.19 (12)
/AMUX4:0: U0:13.2 (VOUT), U5.9 (0)
/AMUX4:1: U0:12.2 (VOUT), U5.8 (1)
/AMUX4:2: U2:11.2 (VOUT), U5.7 (2)
/AMUX4:3: U3:12.2 (VOUT), U5.6 (3)
/AMUX4:4: U1:12.2 (VOUT), U5.5 (4)
/AMUX4:5: U2:12.2 (VOUT), U5.4 (5)
/AMUX4:6: U4:12.2 (VOUT), U5.3 (6)
/AMUX4:7: U2:13.2 (VOUT), U5.2 (7)
/AMUX4:8: U1:13.2 (VOUT), U5.23 (8)
/AMUX4:9: U4:13.2 (VOUT), U5.22 (9)
/AMUX4:10: U3:13.2 (VOUT), U5.21 (10)
/AMUX4:11: U4:14.2 (VOUT), U5.20 (11)
/AMUX4:12: U1:14.2 (VOUT), U5.19 (12)
/AMUX4:13: U0:14.2 (VOUT), U5.18 (13)
/SELECT0: J1.9, U1.10 (A), U2.10 (A), U3.10 (A), U4.10 (A), U5.10 (A)
/SELECT1: J1.10, U1.11 (B), U2.11 (B), U3.11 (B), U4.11 (B), U5.11 (B)
/SELECT2: J1.11, U1.14 (C), U2.14 (C), U3.14 (C), U4.14 (C), U5.14 (C)
/SELECT3: J1.12, U1.13 (D), U2.13 (D), U3.13 (D), U4.13 (D), U5.13 (D)
GND: C68.2, C69.2, C70.2, C71.2, C72.2, J1.1, J1.7, J1.13, J1.14, U0:0.3 (GND), U0:1.3 (GND), U0:2.3 (GND), U0:3.3 (GND), U0:4.3 (GND), U0:5.3 (GND), U0:6.3 (GND), U0:7.3 (GND), U0:8.3 (GND), U0:9.3 (GND), U0:10.3 (GND), U0:11.3 (GND), U0:12.3 (GND), U0:13.3 (GND), U0:14.3 (GND), U1.12 (VSS), U1.15 (INHIBT), U1:0.3 (GND), U1:1.3 (GND), U1:2.3 (GND), U1:3.3 (GND), U1:4.3 (GND), U1:5.3 (GND), U1:6.3 (GND), U1:7.3 (GND), U1:8.3 (GND), U1:9.3 (GND), U1:10.3 (GND), U1:11.3 (GND), U1:12.3 (GND), U1:13.3 (GND), U1:14.3 (GND), U2.12 (VSS), U2.15 (INHIBT), U2:0.3 (GND), U2:1.3 (GND), U2:2.3 (GND), U2:3.3 (GND), U2:4.3 (GND), U2:5.3 (GND), U2:6.3 (GND), U2:7.3 (GND), U2:8.3 (GND), U2:9.3 (GND), U2:10.3 (GND), U2:11.3 (GND), U2:12.3 (GND), U2:13.3 (GND), U3.12 (VSS), U3.15 (INHIBT), U3:1.3 (GND), U3:2.3 (GND), U3:3.3 (GND), U3:4.3 (GND), U3:5.3 (GND), U3:6.3 (GND), U3:7.3 (GND), U3:8.3 (GND), U3:9.3 (GND), U3:10.3 (GND), U3:11.3 (GND), U3:12.3 (GND), U3:13.3 (GND), U4.12 (VSS), U4.15 (INHIBT), U4:1.3 (GND), U4:2.3 (GND), U4:3.3 (GND), U4:5.3 (GND), U4:7.3 (GND), U4:9.3 (GND), U4:10.3 (GND), U4:12.3 (GND), U4:13.3 (GND), U4:14.3 (GND), U5.12 (VSS), U5.15 (INHIBT)

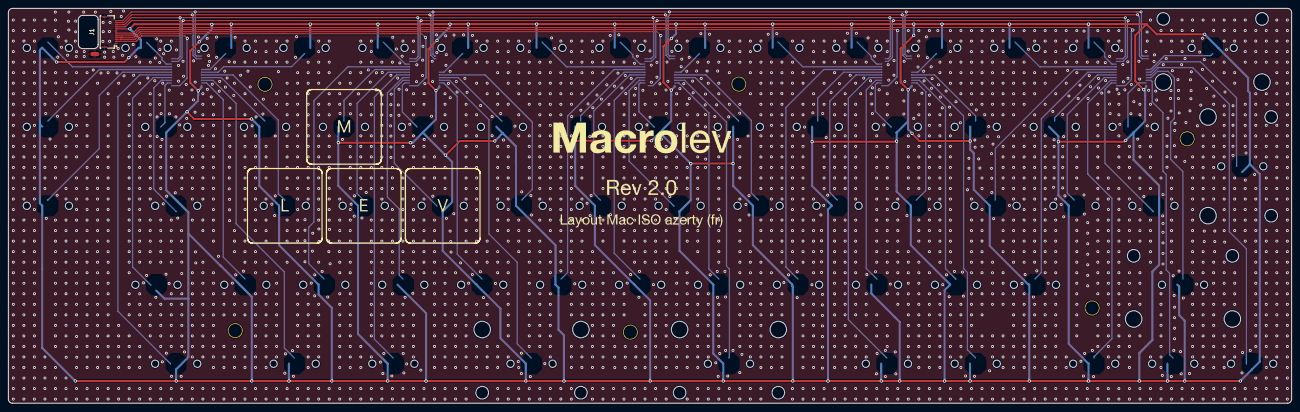
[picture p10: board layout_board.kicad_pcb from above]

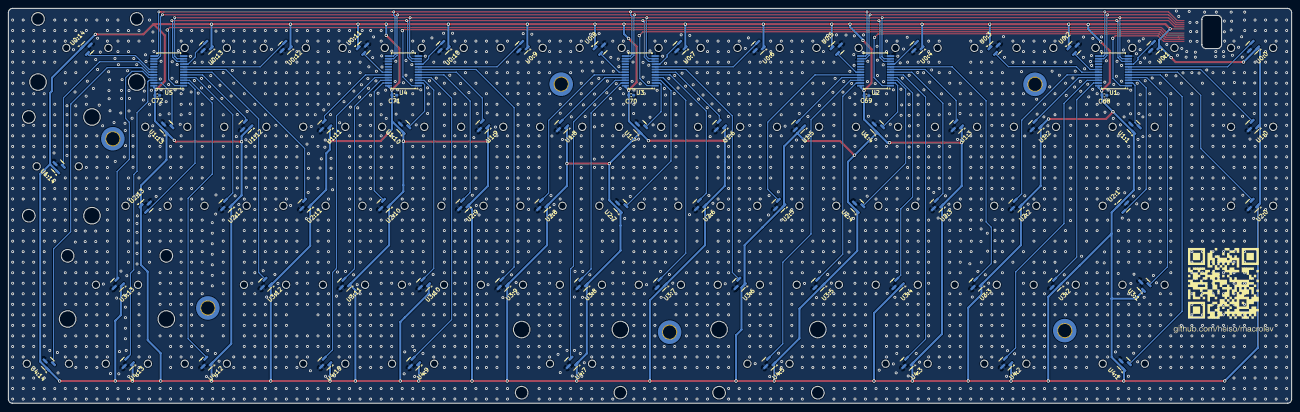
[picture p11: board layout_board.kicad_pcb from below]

Board: 2 copper layers, 309.6 x 95.2 mm, 78 parts (77 on the bottom side), 78 nets.

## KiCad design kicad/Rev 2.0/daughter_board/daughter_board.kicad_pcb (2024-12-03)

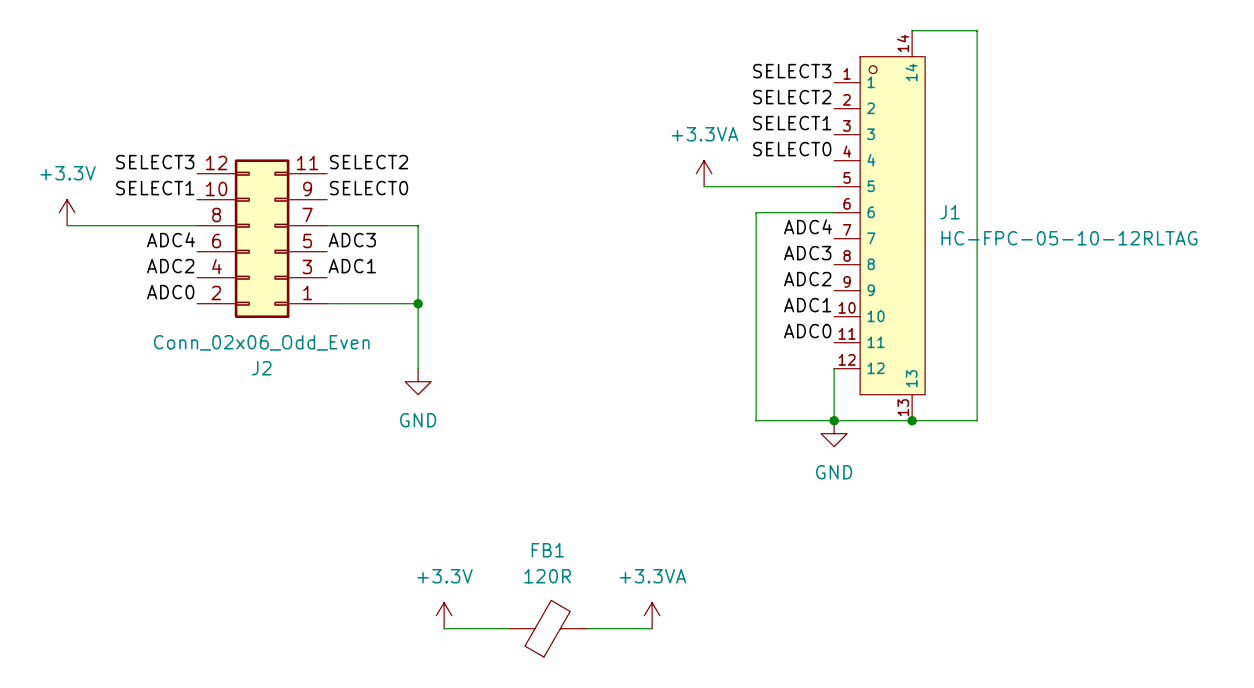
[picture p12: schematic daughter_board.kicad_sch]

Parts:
FB1: 120R; L_0603_1608Metric_Pad1.05x0.95mm_HandSolder; LCSC C76892
J1: HC-FPC-05-10-12RLTAG; FPC-SMD_12P-P0.50_HCTL_HC-FPC-05-10-12RLTAG; LCSC C5213732
J2: Conn_02x06_Odd_Even; PinHeader_2x06_P2.54mm_Horizontal

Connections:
+3.3V: FB1.1, J2.8
+3.3VA: FB1.2, J1.5
/ADC0: J1.11, J2.2
/ADC1: J1.10, J2.3
/ADC2: J1.9, J2.4
/ADC3: J1.8, J2.5
/ADC4: J1.7, J2.6
/SELECT0: J1.4, J2.9
/SELECT1: J1.3, J2.10
/SELECT2: J1.2, J2.11
/SELECT3: J1.1, J2.12
GND: J1.6, J1.12, J1.13, J1.14, J2.1, J2.7

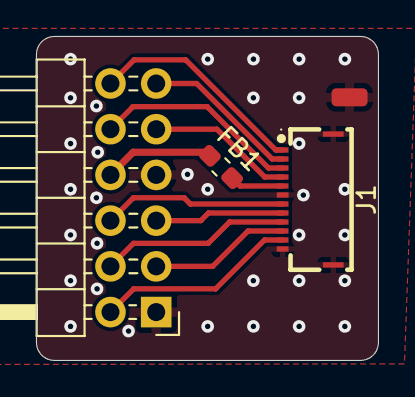
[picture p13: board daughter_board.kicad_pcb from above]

Board: 2 copper layers, 19.0 x 18.0 mm, 3 parts (0 on the bottom side), 12 nets.

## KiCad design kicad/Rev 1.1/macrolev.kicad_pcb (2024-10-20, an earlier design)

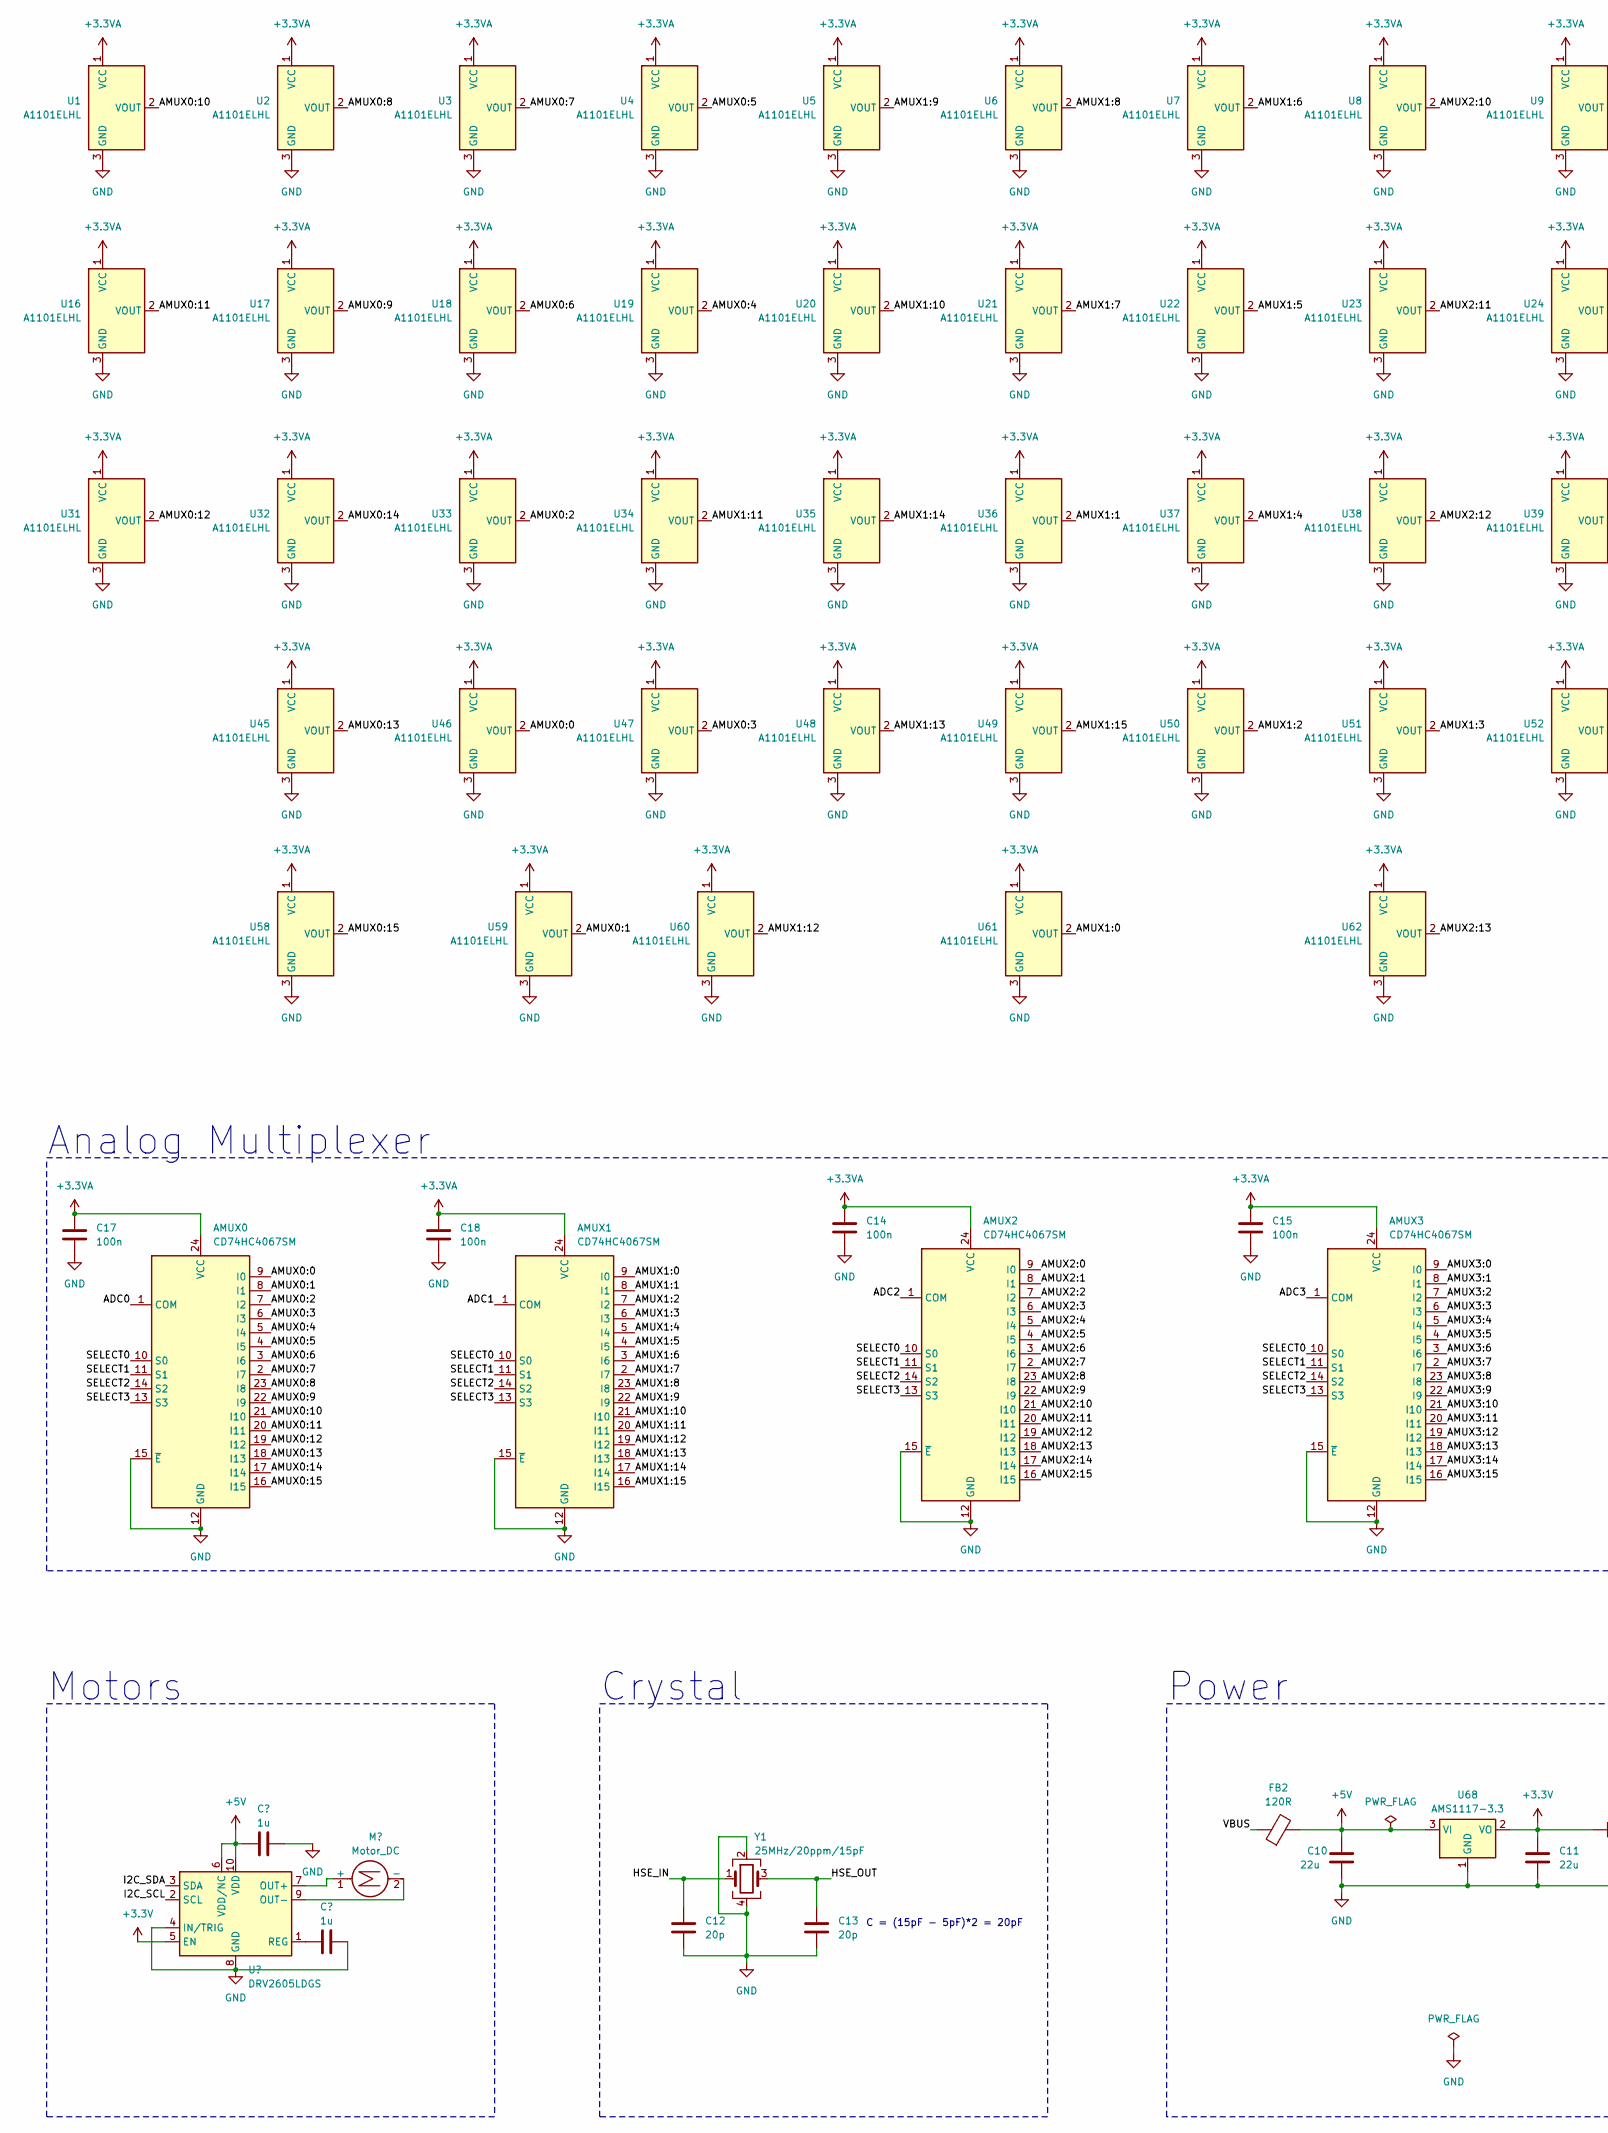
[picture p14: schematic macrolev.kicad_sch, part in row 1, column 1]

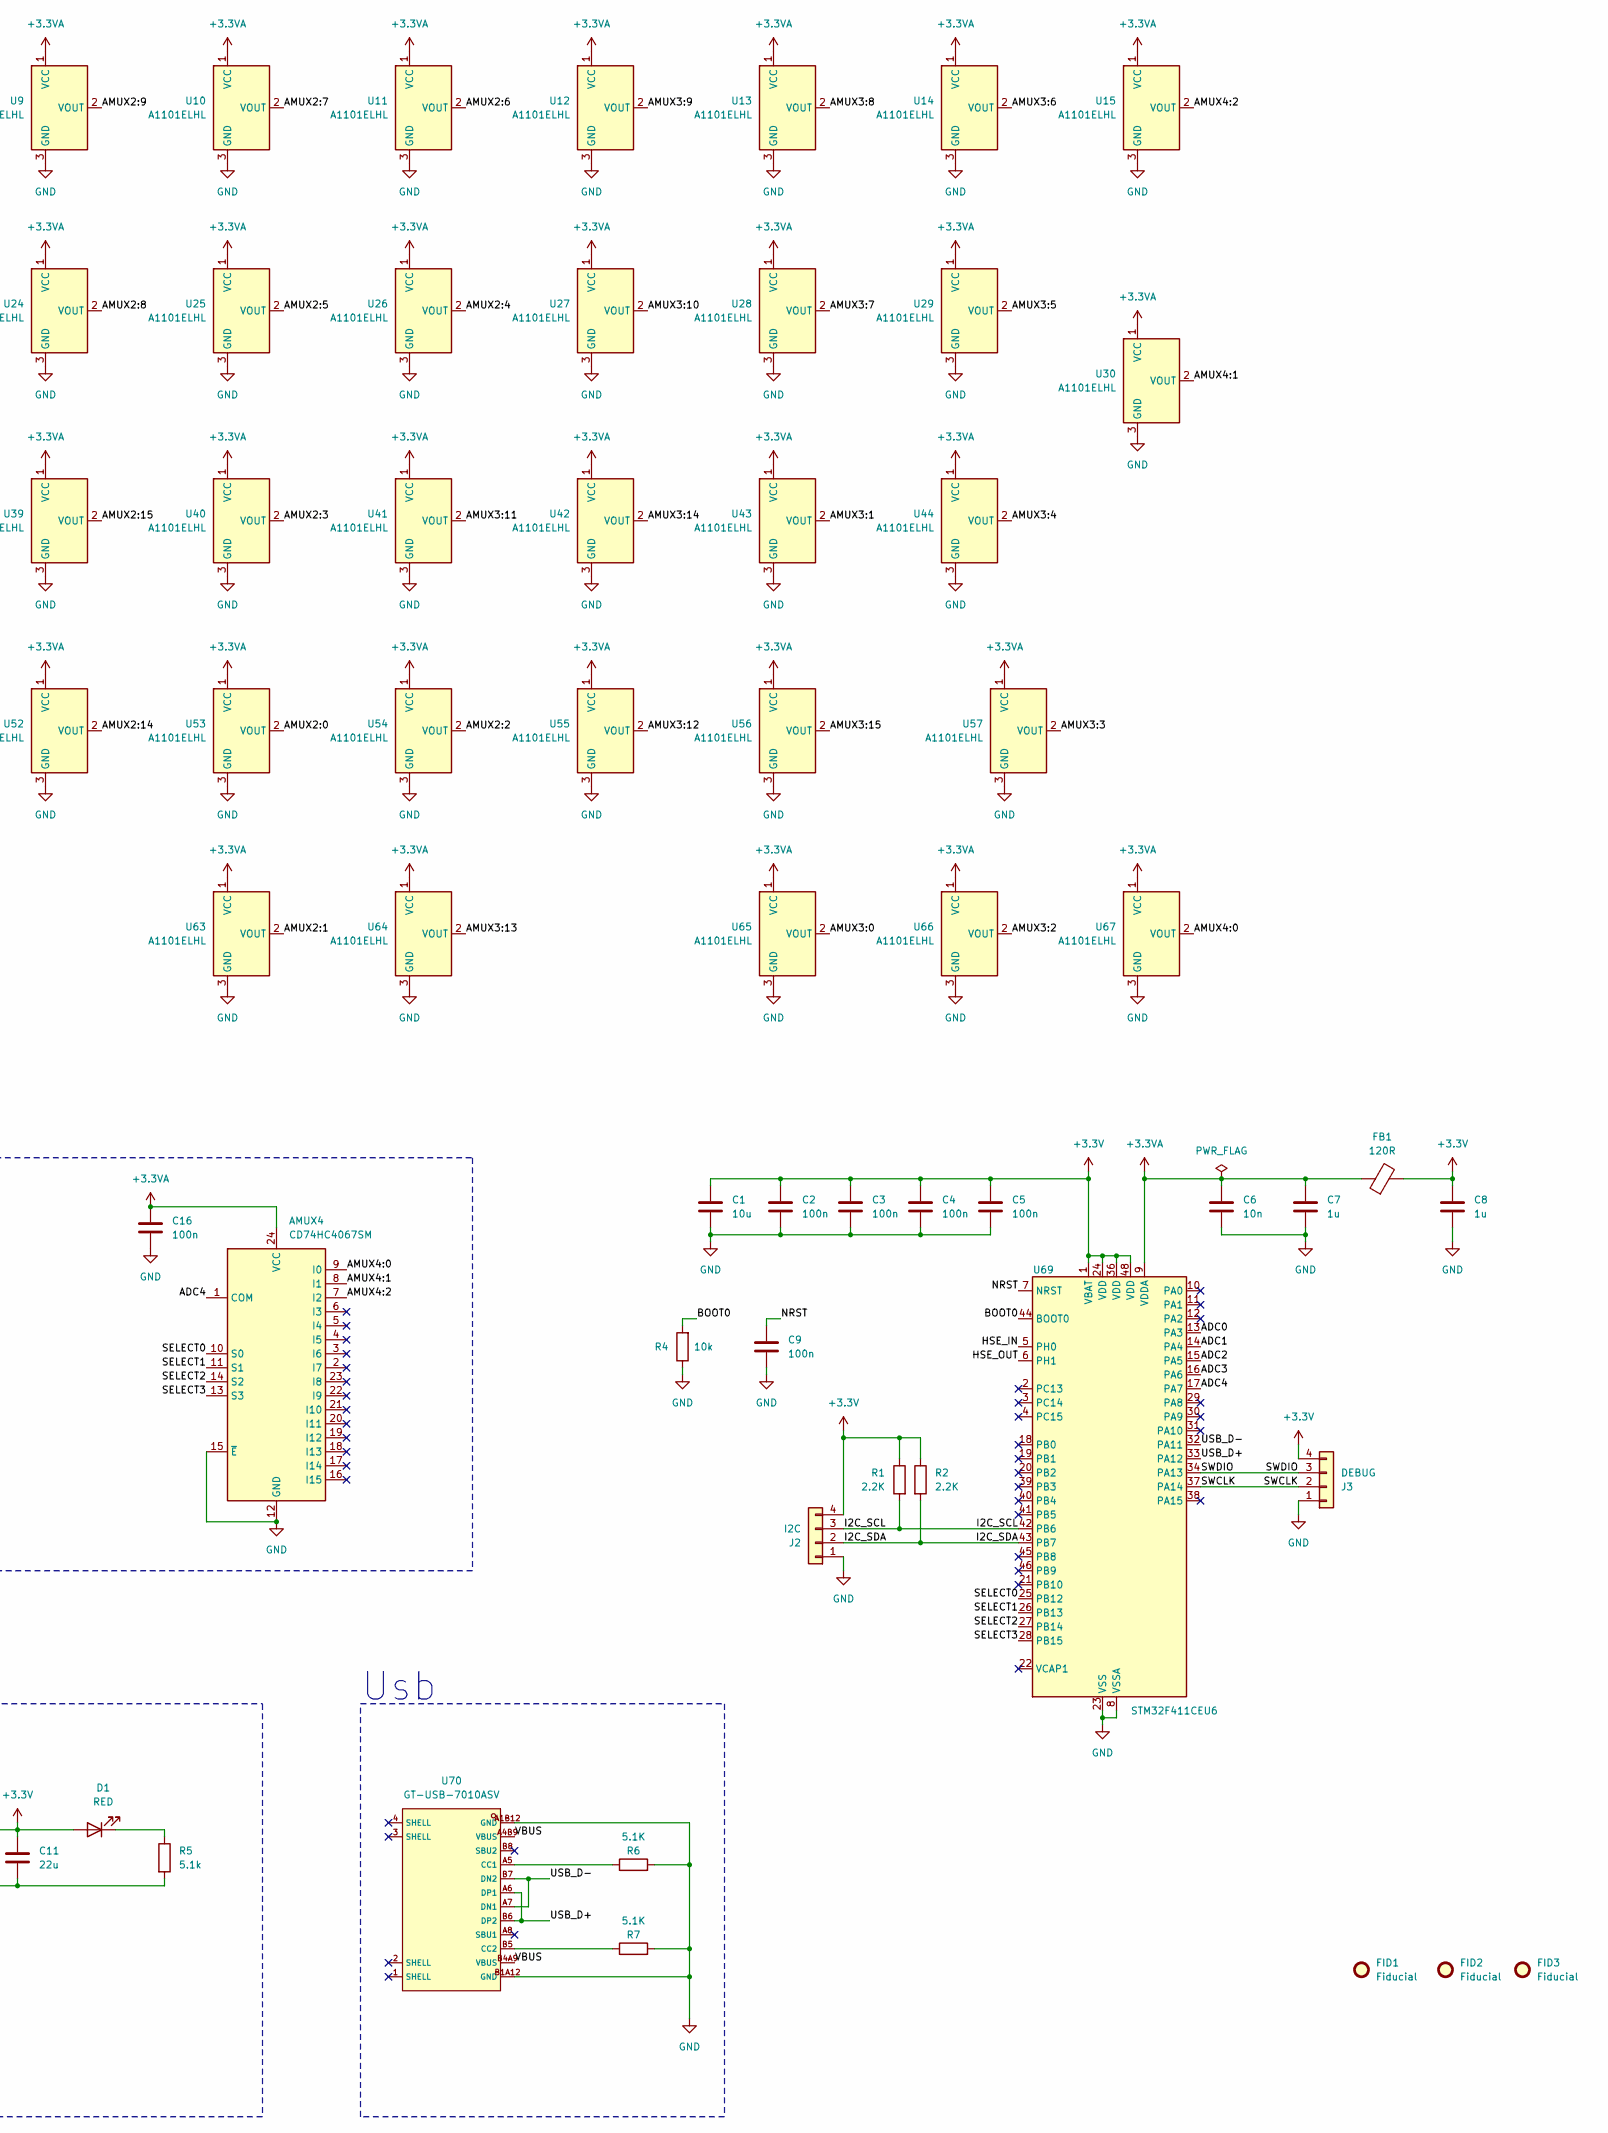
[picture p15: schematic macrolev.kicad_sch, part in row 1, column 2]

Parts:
AMUX0, AMUX1, AMUX2, AMUX3, AMUX4: CD74HC4067SM; SSOP-24_5.3x8.2mm_P0.65mm; LCSC C179326
C1: 10u; C_0603_1608Metric_Pad1.08x0.95mm_HandSolder; LCSC C19702
C2, C3, C4, C5, C9, C14, C15, C16, C17, C18: 100n; C_0402_1005Metric_Pad0.74x0.62mm_HandSolder; LCSC C1525
C6: 10n; C_0402_1005Metric_Pad0.74x0.62mm_HandSolder; LCSC C15195
C7, C8: 1u; C_0402_1005Metric_Pad0.74x0.62mm_HandSolder; LCSC C52923
C10, C11: 22u; C_0805_2012Metric_Pad1.18x1.45mm_HandSolder; LCSC C45783
C12, C13: 20p; C_0402_1005Metric_Pad0.74x0.62mm_HandSolder; LCSC C1554
D1: RED; LED_0603_1608Metric_Pad1.05x0.95mm_HandSolder; LCSC C2286
FB1, FB2: 120R; L_0603_1608Metric_Pad1.05x0.95mm_HandSolder; LCSC C76892
FID1, FID2, FID3: Fiducial; Fiducial_1mm_Mask3mm
J2: I2C; PinHeader_1x04_P2.54mm_Vertical
J3: DEBUG; PinHeader_1x04_P2.54mm_Horizontal
R1, R2: 2.2K; R_0402_1005Metric_Pad0.72x0.64mm_HandSolder; LCSC C25862
R4: 10k; R_0402_1005Metric_Pad0.72x0.64mm_HandSolder; LCSC C25744
R5: 5.1k; R_0402_1005Metric_Pad0.72x0.64mm_HandSolder; LCSC C25905
R6, R7: 5.1K; R_0402_1005Metric_Pad0.72x0.64mm_HandSolder
U1, U2, U3, U4, U5, U6, U7, U8, U9, U10, U11, U12, U13, U14, U15, U16, U17, U18, U19, U20, U21, U22, U23, U24, U25, U26, U27, U28, U29, U30, U31, U32, U33, U34, U35, U36, U37, U38, U39, U40, U41, U42, U43, U44, U45, U46, U47, U48, U49, U50, U51, U52, U53, U54, U55, U56, U57, U58, U59, U60, U61, U62, U63, U64, U65, U66, U67: A1101ELHL; SOT-23; LCSC C266230
U68: AMS1117-3.3; SOT-223-3_TabPin2; LCSC C6186
U69: STM32F411CEU6; QFN-48-1EP_7x7mm_P0.5mm_EP5.6x5.6mm; LCSC C60420
U70: GT-USB-7010ASV; USB-C-SMD_G-SWITCH_GT-USB-7010ASV; LCSC C2988369
Y1: 25MHz/20ppm/15pF; Crystal_SMD_3225-4Pin_3.2x2.5mm_HandSoldering; LCSC C387396

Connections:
+3.3V: C1.1, C2.1, C3.1, C4.1, C5.1, C8.1, C11.1, D1.2 (A), FB1.2, J2.4, J3.4, R1.1, R2.1, U68.2 (VO), U69.1 (VBAT), U69.24 (VDD), U69.36 (VDD), U69.48 (VDD); also elsewhere on the board
+3.3VA: AMUX0.24 (VCC), AMUX1.24 (VCC), AMUX2.24 (VCC), AMUX3.24 (VCC), AMUX4.24 (VCC), C6.1, C7.1, C14.1, C15.1, C16.1, C17.1, C18.1, FB1.1, U1.1 (VCC), U2.1 (VCC), U3.1 (VCC), U4.1 (VCC), U5.1 (VCC), U6.1 (VCC), U7.1 (VCC), U8.1 (VCC), U9.1 (VCC), U10.1 (VCC), U11.1 (VCC), U12.1 (VCC), U13.1 (VCC), U14.1 (VCC), U15.1 (VCC), U16.1 (VCC), U17.1 (VCC), U18.1 (VCC), U19.1 (VCC), U20.1 (VCC), U21.1 (VCC), U22.1 (VCC), U23.1 (VCC), U24.1 (VCC), U25.1 (VCC), U26.1 (VCC), U27.1 (VCC), U28.1 (VCC), U29.1 (VCC), U30.1 (VCC), U31.1 (VCC), U32.1 (VCC), U33.1 (VCC), U34.1 (VCC), U35.1 (VCC), U36.1 (VCC), U37.1 (VCC), U38.1 (VCC), U39.1 (VCC), U40.1 (VCC), U41.1 (VCC), U42.1 (VCC), U43.1 (VCC), U44.1 (VCC), U45.1 (VCC), U46.1 (VCC), U47.1 (VCC), U48.1 (VCC), U49.1 (VCC), U50.1 (VCC), U51.1 (VCC), U52.1 (VCC), U53.1 (VCC), U54.1 (VCC), U55.1 (VCC), U56.1 (VCC), U57.1 (VCC), U58.1 (VCC), U59.1 (VCC), U60.1 (VCC), U61.1 (VCC), U62.1 (VCC), U63.1 (VCC), U64.1 (VCC), U65.1 (VCC), U66.1 (VCC), U67.1 (VCC), U69.9 (VDDA)
+5V: C10.1, FB2.2, U68.3 (VI); also elsewhere on the board
/ADC0: AMUX0.1 (COM), U69.13 (PA3)
/ADC1: AMUX1.1 (COM), U69.14 (PA4)
/ADC2: AMUX2.1 (COM), U69.15 (PA5)
/ADC3: AMUX3.1 (COM), U69.16 (PA6)
/ADC4: AMUX4.1 (COM), U69.17 (PA7)
/AMUX0:0: AMUX0.9 (I0), U46.2 (VOUT)
/AMUX0:1: AMUX0.8 (I1), U59.2 (VOUT)
/AMUX0:2: AMUX0.7 (I2), U33.2 (VOUT)
/AMUX0:3: AMUX0.6 (I3), U47.2 (VOUT)
/AMUX0:4: AMUX0.5 (I4), U19.2 (VOUT)
/AMUX0:5: AMUX0.4 (I5), U4.2 (VOUT)
/AMUX0:6: AMUX0.3 (I6), U18.2 (VOUT)
/AMUX0:7: AMUX0.2 (I7), U3.2 (VOUT)
/AMUX0:8: AMUX0.23 (I8), U2.2 (VOUT)
/AMUX0:9: AMUX0.22 (I9), U17.2 (VOUT)
/AMUX0:10: AMUX0.21 (I10), U1.2 (VOUT)
/AMUX0:11: AMUX0.20 (I11), U16.2 (VOUT)
/AMUX0:12: AMUX0.19 (I12), U31.2 (VOUT)
/AMUX0:13: AMUX0.18 (I13), U45.2 (VOUT)
/AMUX0:14: AMUX0.17 (I14), U32.2 (VOUT)
/AMUX0:15: AMUX0.16 (I15), U58.2 (VOUT)
/AMUX1:0: AMUX1.9 (I0), U61.2 (VOUT)
/AMUX1:1: AMUX1.8 (I1), U36.2 (VOUT)
/AMUX1:2: AMUX1.7 (I2), U50.2 (VOUT)
/AMUX1:3: AMUX1.6 (I3), U51.2 (VOUT)
/AMUX1:4: AMUX1.5 (I4), U37.2 (VOUT)
/AMUX1:5: AMUX1.4 (I5), U22.2 (VOUT)
/AMUX1:6: AMUX1.3 (I6), U7.2 (VOUT)
/AMUX1:7: AMUX1.2 (I7), U21.2 (VOUT)
/AMUX1:8: AMUX1.23 (I8), U6.2 (VOUT)
/AMUX1:9: AMUX1.22 (I9), U5.2 (VOUT)
/AMUX1:10: AMUX1.21 (I10), U20.2 (VOUT)
/AMUX1:11: AMUX1.20 (I11), U34.2 (VOUT)
/AMUX1:12: AMUX1.19 (I12), U60.2 (VOUT)
/AMUX1:13: AMUX1.18 (I13), U48.2 (VOUT)
/AMUX1:14: AMUX1.17 (I14), U35.2 (VOUT)
/AMUX1:15: AMUX1.16 (I15), U49.2 (VOUT)
/AMUX2:0: AMUX2.9 (I0), U53.2 (VOUT)
/AMUX2:1: AMUX2.8 (I1), U63.2 (VOUT)
/AMUX2:2: AMUX2.7 (I2), U54.2 (VOUT)
/AMUX2:3: AMUX2.6 (I3), U40.2 (VOUT)
/AMUX2:4: AMUX2.5 (I4), U26.2 (VOUT)
/AMUX2:5: AMUX2.4 (I5), U25.2 (VOUT)
/AMUX2:6: AMUX2.3 (I6), U11.2 (VOUT)
/AMUX2:7: AMUX2.2 (I7), U10.2 (VOUT)
/AMUX2:8: AMUX2.23 (I8), U24.2 (VOUT)
/AMUX2:9: AMUX2.22 (I9), U9.2 (VOUT)
/AMUX2:10: AMUX2.21 (I10), U8.2 (VOUT)
/AMUX2:11: AMUX2.20 (I11), U23.2 (VOUT)
/AMUX2:12: AMUX2.19 (I12), U38.2 (VOUT)
/AMUX2:13: AMUX2.18 (I13), U62.2 (VOUT)
/AMUX2:14: AMUX2.17 (I14), U52.2 (VOUT)
/AMUX2:15: AMUX2.16 (I15), U39.2 (VOUT)
/AMUX3:0: AMUX3.9 (I0), U65.2 (VOUT)
/AMUX3:1: AMUX3.8 (I1), U43.2 (VOUT)
/AMUX3:2: AMUX3.7 (I2), U66.2 (VOUT)
/AMUX3:3: AMUX3.6 (I3), U57.2 (VOUT)
/AMUX3:4: AMUX3.5 (I4), U44.2 (VOUT)
/AMUX3:5: AMUX3.4 (I5), U29.2 (VOUT)
/AMUX3:6: AMUX3.3 (I6), U14.2 (VOUT)
/AMUX3:7: AMUX3.2 (I7), U28.2 (VOUT)
/AMUX3:8: AMUX3.23 (I8), U13.2 (VOUT)
/AMUX3:9: AMUX3.22 (I9), U12.2 (VOUT)
/AMUX3:10: AMUX3.21 (I10), U27.2 (VOUT)
/AMUX3:11: AMUX3.20 (I11), U41.2 (VOUT)
/AMUX3:12: AMUX3.19 (I12), U55.2 (VOUT)
/AMUX3:13: AMUX3.18 (I13), U64.2 (VOUT)
/AMUX3:14: AMUX3.17 (I14), U42.2 (VOUT)
/AMUX3:15: AMUX3.16 (I15), U56.2 (VOUT)
/AMUX4:0: AMUX4.9 (I0), U67.2 (VOUT)
/AMUX4:1: AMUX4.8 (I1), U30.2 (VOUT)
/AMUX4:2: AMUX4.7 (I2), U15.2 (VOUT)
/BOOT0: R4.2, U69.44 (BOOT0)
/HSE_IN: C12.1, U69.5 (PH0), Y1.1
/HSE_OUT: C13.1, U69.6 (PH1), Y1.3
/I2C_SCL: J2.3, R1.2, U69.42 (PB6)
/I2C_SDA: J2.2, R2.2, U69.43 (PB7)
/NRST: C9.1, U69.7 (NRST)
/SELECT0: AMUX0.10 (S0), AMUX1.10 (S0), AMUX2.10 (S0), AMUX3.10 (S0), AMUX4.10 (S0), U69.25 (PB12)
/SELECT1: AMUX0.11 (S1), AMUX1.11 (S1), AMUX2.11 (S1), AMUX3.11 (S1), AMUX4.11 (S1), U69.26 (PB13)
/SELECT2: AMUX0.14 (S2), AMUX1.14 (S2), AMUX2.14 (S2), AMUX3.14 (S2), AMUX4.14 (S2), U69.27 (PB14)
/SELECT3: AMUX0.13 (S3), AMUX1.13 (S3), AMUX2.13 (S3), AMUX3.13 (S3), AMUX4.13 (S3), U69.28 (PB15)
/SWCLK: J3.2, U69.37 (PA14)
/SWDIO: J3.3, U69.34 (PA13)
/USB_D+: U69.33 (PA12), U70.A6 (DP1), U70.B6 (DP2)
/USB_D-: U69.32 (PA11), U70.A7 (DN1), U70.B7 (DN2)
/VBUS: FB2.1, U70.A4B9 (VBUS), U70.B4A9 (VBUS); also elsewhere on the board
GND: AMUX0.12 (GND), AMUX0.15 (~E), AMUX1.12 (GND), AMUX1.15 (~E), AMUX2.12 (GND), AMUX2.15 (~E), AMUX3.12 (GND), AMUX3.15 (~E), AMUX4.12 (GND), AMUX4.15 (~E), C1.2, C2.2, C3.2, C4.2, C5.2, C6.2, C7.2, C8.2, C9.2, C10.2, C11.2, C12.2, C13.2, C14.2, C15.2, C16.2, C17.2, C18.2, J2.1, J3.1, R4.1, R5.2, R6.2, R7.2, U1.3 (GND), U2.3 (GND), U3.3 (GND), U4.3 (GND), U5.3 (GND), U6.3 (GND), U7.3 (GND), U8.3 (GND), U9.3 (GND), U10.3 (GND), U11.3 (GND), U12.3 (GND), U13.3 (GND), U14.3 (GND), U15.3 (GND), U16.3 (GND), U17.3 (GND), U18.3 (GND), U19.3 (GND), U20.3 (GND), U21.3 (GND), U22.3 (GND), U23.3 (GND), U24.3 (GND), U25.3 (GND), U26.3 (GND), U27.3 (GND), U28.3 (GND), U29.3 (GND), U30.3 (GND), U31.3 (GND), U32.3 (GND), U33.3 (GND), U34.3 (GND), U35.3 (GND), U36.3 (GND), U37.3 (GND), U38.3 (GND), U39.3 (GND), U40.3 (GND), U41.3 (GND), U42.3 (GND), U43.3 (GND), U44.3 (GND), U45.3 (GND), U46.3 (GND), U47.3 (GND), U48.3 (GND), U49.3 (GND), U50.3 (GND), U51.3 (GND), U52.3 (GND), U53.3 (GND), U54.3 (GND), U55.3 (GND), U56.3 (GND), U57.3 (GND), U58.3 (GND), U59.3 (GND), U60.3 (GND), U61.3 (GND), U62.3 (GND), U63.3 (GND), U64.3 (GND), U65.3 (GND), U66.3 (GND), U67.3 (GND), U68.1 (GND), U69.8 (VSSA), U69.23 (VSS), U69.35 (VSS), U69.47 (VSS), U69.49 (VSS), U70.A1B12 (GND), U70.B1A12 (GND), Y1.2, Y1.4; also elsewhere on the board
unnamed: D1.1 (K), R5.1
unnamed: R6.1, U70.A5 (CC1)
unnamed: R7.1, U70.B5 (CC2)

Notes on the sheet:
Usb
Power
Motors
C = (15pF - 5pF)*2 = 20pF
Crystal
Analog Multiplexer

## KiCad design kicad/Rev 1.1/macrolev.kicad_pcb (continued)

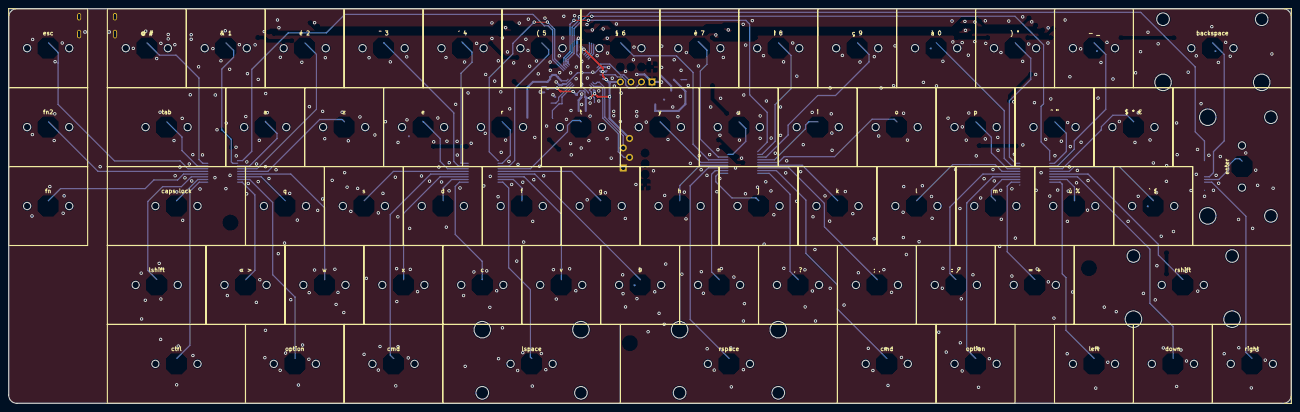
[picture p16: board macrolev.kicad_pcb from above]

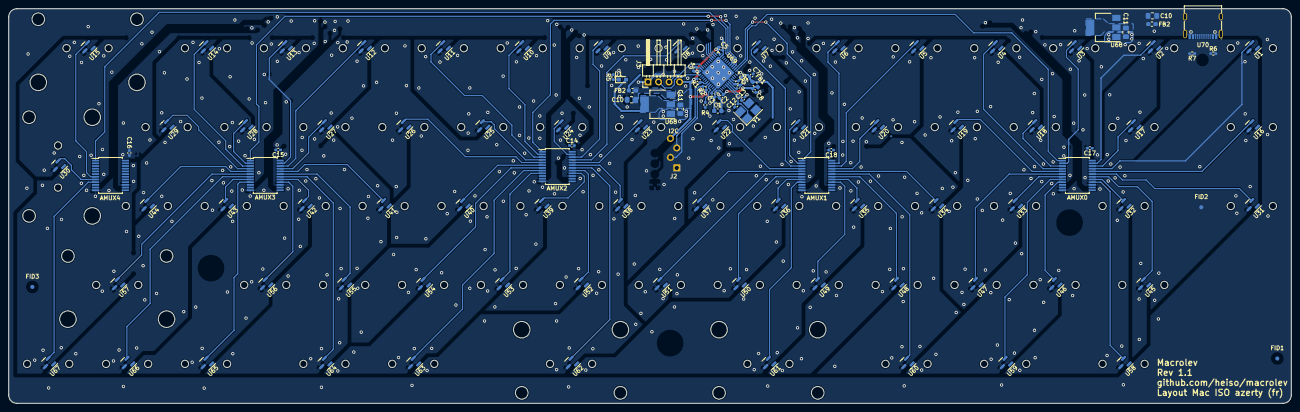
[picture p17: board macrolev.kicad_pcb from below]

Board: 4 copper layers, 309.6 x 95.2 mm, 179 parts (112 on the bottom side), 94 nets.

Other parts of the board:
! 8: SW_MX_Lekker_1u
" 3: SW_MX_Lekker_1u
$ * €: SW_MX_Lekker_1u
& 1: SW_MX_Lekker_1u
' 4: SW_MX_Lekker_1u
( 5: SW_MX_Lekker_1u
) °: SW_MX_Lekker_1u
, ?: SW_MX_Lekker_1u
- _: SW_MX_Lekker_1u
: /: SW_MX_Lekker_1u
; .: SW_MX_Lekker_1u
< >: SW_MX_Lekker_1u
= +: SW_MX_Lekker_1u
@ #: SW_MX_Lekker_1u
C10#2, C11#2: 22u; C_0805_2012Metric_Pad1.18x1.45mm_HandSolder
FB2#2: 120R; L_0603_1608Metric_Pad1.05x0.95mm_HandSolder
U68#2: AMS1117-3.3; SOT-223-3_TabPin2
^ ¨: SW_MX_Lekker_1u
` £: SW_MX_Lekker_1u
a: SW_MX_Lekker_1u
b: SW_MX_Lekker_1u
backspace: SW_MX_Lekker
c: SW_MX_Lekker_1u
caps lock: SW_MX_Lekker_1.75u
cmd: SW_MX_Lekker_1.25u
cmd#2: SW_MX_Lekker_1.25u
ctrl: SW_MX_Lekker_1.75u
d: SW_MX_Lekker_1u
down: SW_MX_Lekker_1u
e: SW_MX_Lekker_1u
enter: SW_MX_Lekker
esc: SW_MX_Lekker_1u
f: SW_MX_Lekker_1u
fn, fn2: SW_MX_Lekker_1u
g: SW_MX_Lekker_1u
h: SW_MX_Lekker_1u
i: SW_MX_Lekker_1u
j: SW_MX_Lekker_1u
k: SW_MX_Lekker_1u
l: SW_MX_Lekker_1u
left: SW_MX_Lekker_1u
lshift: SW_MX_Lekker_1.25u
lspace: SW_MX_Lekker
m: SW_MX_Lekker_1u
n: SW_MX_Lekker_1u
o: SW_MX_Lekker_1u
option: SW_MX_Lekker_1.25u
option#2: SW_MX_Lekker_1u
p: SW_MX_Lekker_1u
q: SW_MX_Lekker_1u
r: SW_MX_Lekker_1u
right: SW_MX_Lekker_1u
rshift: SW_MX_Lekker
rspace: SW_MX_Lekker
s: SW_MX_Lekker_1u
t: SW_MX_Lekker_1u
tab: SW_MX_Lekker_1.5u
u: SW_MX_Lekker_1u
v: SW_MX_Lekker_1u
w: SW_MX_Lekker_1u
x: SW_MX_Lekker_1u
y: SW_MX_Lekker_1u
z: SW_MX_Lekker_1u
§ 6: SW_MX_Lekker_1u
à 0: SW_MX_Lekker_1u
ç 9: SW_MX_Lekker_1u
è 7: SW_MX_Lekker_1u
é 2: SW_MX_Lekker_1u
ù %: SW_MX_Lekker_1u

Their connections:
+3.3V: C11#2.1, U68#2.2 (VO); also elsewhere on the board
+5V: C10#2.1, FB2#2.2, U68#2.3 (VI); also elsewhere on the board
/VBUS: FB2#2.1; also elsewhere on the board
GND: C10#2.2, C11#2.2, U68#2.1 (GND); also elsewhere on the board

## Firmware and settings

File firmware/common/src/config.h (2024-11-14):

#ifndef __CONFIG_H
#define __CONFIG_H

#include <stdint.h>

#define DEFAULT_TRIGGER_OFFSET 64
#define DEFAULT_RESET_THRESHOLD 3
#define DEFAULT_RAPID_TRIGGER_OFFSET 40
#define DEFAULT_SCREAMING_VELOCITY_TRIGGER 45
#define DEFAULT_TAP_TIMEOUT 200

#define ADC_CHANNEL_COUNT 5
#define AMUX_SELECT_PINS_COUNT 4
#define AMUX_CHANNEL_COUNT 16

#define MATRIX_ROWS 5
#define MATRIX_COLS 15

extern const struct user_config keyboard_default_user_config;
extern const uint8_t channels_by_row_col[MATRIX_ROWS][MATRIX_COLS][2];

#endif /* __CONFIG_H */

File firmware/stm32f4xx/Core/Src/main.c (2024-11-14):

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
/* Includes ------------------------------------------------------------------*/
#include "main.h"

/* USER CODE BEGIN Includes */
#include "DRV2605L.h"
#include "config.h"
#include "hid.h"
#include "keyboard.h"
#include <string.h>

/* USER CODE END Includes */

/* USER CODE BEGIN PD */

#define IS_DRV2605_ENABLED false

/* USER CODE END PD */

ADC_HandleTypeDef hadc1;

I2C_HandleTypeDef hi2c1;

PCD_HandleTypeDef hpcd_USB_OTG_FS;

/* USER CODE BEGIN PV */
ADC_ChannelConfTypeDef ADC_channel_Config = {0};

extern struct user_config keyboard_user_config;

const uint32_t adc_channels[ADC_CHANNEL_COUNT] = {ADC_CHANNEL_3, ADC_CHANNEL_4, ADC_CHANNEL_5, ADC_CHANNEL_6, ADC_CHANNEL_7};
const uint32_t amux_select_pins[AMUX_SELECT_PINS_COUNT] = {GPIO_PIN_12, GPIO_PIN_13, GPIO_PIN_14, GPIO_PIN_15};

/* USER CODE END PV */

void SystemClock_Config(void);
static void MX_GPIO_Init(void);
static void MX_ADC1_Init(void);
static void MX_USB_OTG_FS_PCD_Init(void);
#if IS_DRV2605_ENABLED
static void MX_I2C1_Init(void);
#endif
/* USER CODE BEGIN 0 */

uint8_t readRegister8(uint8_t reg) {
  uint8_t buffer[1] = {reg};
  HAL_I2C_Master_Transmit(&hi2c1, DRV2605_ADDR << 1, buffer, 1, 1000);
  HAL_I2C_Master_Receive(&hi2c1, DRV2605_ADDR << 1, buffer, 1, 1000);
  return buffer[0];
}

void writeRegister8(uint8_t reg, uint8_t val) {
  uint8_t buffer[2] = {reg, val};
  HAL_I2C_Master_Transmit(&hi2c1, DRV2605_ADDR << 1, buffer, sizeof(buffer), 1);
}

void DRV2605_init() {
  writeRegister8(DRV2605_REG_MODE, 0x00); // out of standby

  writeRegister8(DRV2605_REG_RTPIN, 0x00); // no real-time-playback

  writeRegister8(DRV2605_REG_WAVESEQ1, 1); // strong click
  writeRegister8(DRV2605_REG_WAVESEQ2, 0); // end sequence

  writeRegister8(DRV2605_REG_OVERDRIVE, 1); // no overdrive

  writeRegister8(DRV2605_REG_SUSTAINPOS, 0);
  writeRegister8(DRV2605_REG_SUSTAINNEG, 0);
  writeRegister8(DRV2605_REG_BREAK, 0);
  writeRegister8(DRV2605_REG_AUDIOMAX, 0x64);

  // ERM open loop

  // turn on N_ERM_LRA
  writeRegister8(DRV2605_REG_FEEDBACK,
                 readRegister8(DRV2605_REG_FEEDBACK) | 0x80);

  // // turn off N_ERM_LRA
  // writeRegister8(DRV2605_REG_FEEDBACK,
  //                readRegister8(DRV2605_REG_FEEDBACK) & 0x7F);
  // // turn on ERM_OPEN_LOOP
  // writeRegister8(DRV2605_REG_CONTROL3,
  //                readRegister8(DRV2605_REG_CONTROL3) | 0x20);

  writeRegister8(DRV2605_REG_LIBRARY, 1);
  writeRegister8(DRV2605_REG_MODE, DRV2605_MODE_INTTRIG);
}
/* USER CODE END 0 */

/**
 * @brief  The application entry point.
 * @retval int
 */
int main(void) {

  /* MCU Configuration--------------------------------------------------------*/

  /* Reset of all peripherals, Initializes the Flash interface and the Systick. */
  HAL_Init();

  /* Configure the system clock */
  SystemClock_Config();

  /* Initialize all configured peripherals */
  MX_GPIO_Init();
  MX_ADC1_Init();
  MX_USB_OTG_FS_PCD_Init();
#if IS_DRV2605_ENABLED
  MX_I2C1_Init();
#endif
  /* USER CODE BEGIN 2 */

  ADC_channel_Config.Rank = 1;
  ADC_channel_Config.SamplingTime = ADC_SAMPLETIME_3CYCLES;
  keyboard_init_keys();

  hid_init();
#if IS_DRV2605_ENABLED
  drv2605l_init();
#endif

  /* USER CODE END 2 */

  /* Infinite loop */
  /* USER CODE BEGIN WHILE */
  while (1) {
    // MARK: Main loop
    keyboard_task();

    hid_task();

#if IS_DRV2605_ENABLED
    if (key_triggered) {
      writeRegister8(DRV2605_REG_WAVESEQ1 + 0, 1);
      writeRegister8(DRV2605_REG_WAVESEQ1 + 1, 0);
      writeRegister8(DRV2605_REG_GO, 1);
    }
#endif
    /* USER CODE END WHILE */

    /* USER CODE BEGIN 3 */
  }
  /* USER CODE END 3 */
}

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
/* USER CODE BEGIN 4 */

// MARK: keyboard_* functions

void keyboard_read_config() {
  memcpy(&keyboard_user_config, (uint32_t *)CONFIG_ADDRESS, sizeof(keyboard_user_config));
}

uint8_t keyboard_write_config(uint8_t *buffer, uint16_t offset, uint16_t size) {
  if (offset >= sizeof(keyboard_user_config)) {
    return 0;
  }

  HAL_FLASH_Unlock();
  __HAL_FLASH_CLEAR_FLAG(FLASH_FLAG_EOP | FLASH_FLAG_OPERR | FLASH_FLAG_WRPERR | FLASH_FLAG_PGAERR | FLASH_FLAG_PGSERR);
  FLASH_Erase_Sector(FLASH_SECTOR_6, VOLTAGE_RANGE_3);
  for (uint16_t i = offset; i < size; i++) {
    if (HAL_FLASH_Program(FLASH_TYPEPROGRAM_BYTE, CONFIG_ADDRESS + i, buffer[i]) != HAL_OK) {
      HAL_FLASH_Lock();
    };
  }
  HAL_FLASH_Lock();
  return 1;
}

void keyboard_select_amux(uint8_t amux_channel) {
  // TODO: set GPIOs at the same time using bitmap on register
  for (uint8_t i = 0; i < AMUX_SELECT_PINS_COUNT; i++) {
    HAL_GPIO_WritePin(GPIOB, amux_select_pins[i], (amux_channel >> i) & 1);
  }
}

void keyboard_select_adc(uint8_t adc_channel) {
  ADC_channel_Config.Channel = adc_channels[adc_channel];
  HAL_ADC_ConfigChannel(&hadc1, &ADC_channel_Config);
  HAL_ADC_Start(&hadc1);
  HAL_ADC_PollForConversion(&hadc1, 1);
}

uint16_t keyboard_read_adc() {
  return HAL_ADC_GetValue(&hadc1);
}

void keyboard_close_adc() {
  HAL_ADC_Stop(&hadc1);
}

uint32_t keyboard_get_time() {
  return HAL_GetTick();
}

/* USER CODE END 4 */
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


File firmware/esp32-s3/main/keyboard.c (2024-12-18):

#include "keyboard.h"
#include "DRV2605L.h"
#include "esp_log.h"
#include "hid.h"
#include <class/hid/hid.h>
#include <stdlib.h>

// const static char *TAG = "MACROLEV";

struct key keyboard_keys[ADC_CHANNEL_COUNT][AMUX_CHANNEL_COUNT] = {0};

struct user_config keyboard_user_config = {0};

static uint8_t key_triggered = 0;

uint8_t get_bitmask_for_modifier(uint8_t keycode) {
  switch (keycode) {
  case HID_KEY_CONTROL_LEFT:
    return 0b00000001;
  case HID_KEY_SHIFT_LEFT:
    return 0b00000010;
  case HID_KEY_ALT_LEFT:
    return 0b00000100;
  case HID_KEY_GUI_LEFT:
    return 0b00001000;
  case HID_KEY_CONTROL_RIGHT:
    return 0b00010000;
  case HID_KEY_SHIFT_RIGHT:
    return 0b00100000;
  case HID_KEY_ALT_RIGHT:
    return 0b01000000;
  case HID_KEY_GUI_RIGHT:
    return 0b10000000;
  default:
    return 0b00000000;
  }
}

uint16_t get_usage_consumer_control(uint16_t value) {
  if (value > 0xFF) {
    return value & 0b0111111111111111;
  } else {
    return 0;
  }
}

void init_key(uint8_t adc_channel, uint8_t amux_channel, uint8_t row, uint8_t column) {
  struct key *key = &keyboard_keys[adc_channel][amux_channel];

  key->is_enabled = 1;
  key->is_idle = 0;
  key->row = row;
  key->column = column;

  key->calibration.cycles_count = 0;
  key->calibration.idle_value = IDLE_VALUE_APPROX;
  key->calibration.max_distance = MAX_DISTANCE_APPROX;

  key->actuation.status = STATUS_RESET;
  key->actuation.trigger_offset = keyboard_user_config.trigger_offset;
  key->actuation.reset_offset = keyboard_user_config.trigger_offset - keyboard_user_config.reset_threshold;
  key->actuation.rapid_trigger_offset = keyboard_user_config.rapid_trigger_offset;
  key->actuation.is_continuous_rapid_trigger_enabled = 0;

  for (uint8_t i = 0; i < LAYERS_COUNT; i++) {
    if (keyboard_user_config.keymaps[i][row][column] != ____) {
      uint16_t usage_consumer_control = get_usage_consumer_control(keyboard_user_config.keymaps[i][row][column]);
      if (usage_consumer_control) {
        key->layers[i].type = KEY_TYPE_CONSUMER_CONTROL;
        key->layers[i].value = usage_consumer_control;
      } else {
        uint8_t bitmask = get_bitmask_for_modifier(keyboard_user_config.keymaps[i][row][column]);
        if (bitmask) {
          key->layers[i].type = KEY_TYPE_MODIFIER;
          key->layers[i].value = bitmask;
        } else {
          key->layers[i].type = KEY_TYPE_NORMAL;
          key->layers[i].value = keyboard_user_config.keymaps[i][row][column];
        }
      }
    }
  }
}

uint8_t update_key_state(struct key *key) {
  struct state state;

  // Get a reading
  state.value = keyboard_read_adc();

  if (key->calibration.cycles_count < CALIBRATION_CYCLES) {
    // Calibrate idle value
    float delta = 0.6;
    key->calibration.idle_value = (1 - delta) * state.value + delta * key->calibration.idle_value;
    key->calibration.cycles_count++;

    return 0;
  }

  // Calibrate idle value
  if (state.value > key->calibration.idle_value) {
    // opti possible sur float
    float delta = 0.8;
    key->calibration.idle_value = (1 - delta) * state.value + delta * key->calibration.idle_value;
    state.value = key->calibration.idle_value;
  }

  // Do nothing if key is idle
  if (key->state.distance == 0 && state.value >= key->calibration.idle_value - IDLE_VALUE_OFFSET) {
    if (key->idle_counter >= IDLE_CYCLES_UNTIL_SLEEP) {
      key->is_idle = 1;
      return 0;
    }
    key->idle_counter++;
  }

  // Get distance from top
  if (state.value >= key->calibration.idle_value - IDLE_VALUE_OFFSET) {
    state.distance = 0;
    key->actuation.direction_changed_point = 0;
  } else {
    state.distance = key->calibration.idle_value - IDLE_VALUE_OFFSET - state.value;
    key->is_idle = 0;
    key->idle_counter = 0;
  }

  // Calibrate max distance value
  if (state.distance > key->calibration.max_distance) {
    key->calibration.max_distance = state.distance;
  }

  // Limit max distance
  if (state.distance >= key->calibration.max_distance - MAX_DISTANCE_OFFSET) {
    state.distance = key->calibration.max_distance;
  }

  // Map distance in percentages
  state.distance_8bits = (state.distance * 0xff) / key->calibration.max_distance;

  float delta = 0.8;
  state.filtered_distance = (1 - delta) * state.distance_8bits + delta * key->state.filtered_distance;
  state.filtered_distance_8bits = state.filtered_distance;

  // Update velocity
  state.velocity = state.filtered_distance_8bits - key->state.filtered_distance_8bits;
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

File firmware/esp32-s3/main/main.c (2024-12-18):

#include "config.h"
#include "driver/gpio.h"
#include "esp_adc/adc_cali.h"
#include "esp_adc/adc_cali_scheme.h"
#include "esp_adc/adc_oneshot.h"
#include "esp_log.h"
#include "esp_timer.h"
#include "freertos/FreeRTOS.h"
#include "freertos/task.h"
#include "hid.h"
#include "keyboard.h"
#include "soc/soc_caps.h"
#include <stdio.h>
#include <stdlib.h>
#include <string.h>

const static char *TAG = "MACROLEV";

#define CONFIG_ADDRESS 0x42000000

#define GPIO_SELECT_0 5
#define GPIO_SELECT_1 6
#define GPIO_SELECT_2 9
#define GPIO_SELECT_3 10
/*
 * Let's say, GPIO_SELECT_0=18, GPIO_SELECT_1=19
 * In binary representation,
 * 1ULL<<GPIO_SELECT_0 is equal to 0000000000000000000001000000000000000000 and
 * 1ULL<<GPIO_SELECT_1 is equal to 0000000000000000000010000000000000000000
 * GPIO_OUTPUT_PIN_SEL                0000000000000000000011000000000000000000
 * */
#define GPIO_OUTPUT_PIN_SEL ((1ULL << GPIO_SELECT_0) | (1ULL << GPIO_SELECT_1) | (1ULL << GPIO_SELECT_2) | (1ULL << GPIO_SELECT_3))

adc_oneshot_unit_handle_t adc_handle;
adc_channel_t adc_channel;

extern struct user_config keyboard_user_config;

const uint32_t adc_channels[ADC_CHANNEL_COUNT] = {ADC_CHANNEL_7, ADC_CHANNEL_6, ADC_CHANNEL_5, ADC_CHANNEL_4, ADC_CHANNEL_3};
const uint32_t amux_select_pins[AMUX_SELECT_PINS_COUNT] = {GPIO_SELECT_0, GPIO_SELECT_1, GPIO_SELECT_2, GPIO_SELECT_3};

/*---------------------------------------------------------------
        ADC Calibration
---------------------------------------------------------------*/
static bool adc_calibration_init(adc_unit_t unit, adc_channel_t channel, adc_atten_t atten, adc_cali_handle_t *out_handle) {
  adc_cali_handle_t handle = NULL;
  esp_err_t ret = ESP_FAIL;
  bool calibrated = false;

#if ADC_CALI_SCHEME_CURVE_FITTING_SUPPORTED
  if (!calibrated) {
    ESP_LOGI(TAG, "calibration scheme version is %s", "Curve Fitting");
    adc_cali_curve_fitting_config_t cali_config = {
        .unit_id = unit,
        .chan = channel,
        .atten = atten,
        .bitwidth = ADC_BITWIDTH_DEFAULT,
    };
    ret = adc_cali_create_scheme_curve_fitting(&cali_config, &handle);
    if (ret == ESP_OK) {
      calibrated = true;
    }
  }
#endif

#if ADC_CALI_SCHEME_LINE_FITTING_SUPPORTED
  if (!calibrated) {
    ESP_LOGI(TAG, "calibration scheme version is %s", "Line Fitting");
    adc_cali_line_fitting_config_t cali_config = {
        .unit_id = unit,
        .atten = atten,
        .bitwidth = ADC_BITWIDTH_DEFAULT,
    };
    ret = adc_cali_create_scheme_line_fitting(&cali_config, &handle);
    if (ret == ESP_OK) {
      calibrated = true;
    }
  }
#endif

  *out_handle = handle;
  if (ret == ESP_OK) {
    ESP_LOGI(TAG, "Calibration Success");
  } else if (ret == ESP_ERR_NOT_SUPPORTED || !calibrated) {
    ESP_LOGW(TAG, "eFuse not burnt, skip software calibration");
  } else {
    ESP_LOGE(TAG, "Invalid arg or no memory");
  }

  return calibrated;
}

static void adc_init() {
  //-------------ADC Init---------------//
  adc_oneshot_unit_init_cfg_t init_config = {
      .unit_id = ADC_UNIT_2,
  };
  ESP_ERROR_CHECK(adc_oneshot_new_unit(&init_config, &adc_handle));

  //-------------ADC Config---------------//
  adc_oneshot_chan_cfg_t config = {
      .bitwidth = ADC_BITWIDTH_DEFAULT,
      .atten = ADC_ATTEN_DB_12,
  };

  for (uint8_t i = 0; i < ADC_CHANNEL_COUNT; i++) {
    ESP_ERROR_CHECK(adc_oneshot_config_channel(adc_handle, adc_channels[i], &config));
    //-------------ADC Calibration Init---------------//
    adc_cali_handle_t adc_cali_chan_handle = NULL;
    adc_calibration_init(ADC_UNIT_2, adc_channels[i], ADC_ATTEN_DB_12, &adc_cali_chan_handle);
  }
}

void gpio_init() {
  // zero-initialize the config structure.
  gpio_config_t gpio_conf = {
      // disable interrupt
      .intr_type = GPIO_INTR_DISABLE,
      // set as output mode
      .mode = GPIO_MODE_OUTPUT,
      // bit mask of the pins that you want to set
      .pin_bit_mask = GPIO_OUTPUT_PIN_SEL,
      // disable pull-down mode
      .pull_down_en = 0,
      // disable pull-up mode
      .pull_up_en = 0,
  };

  gpio_config(&gpio_conf);
}

void app_main(void) {
  gpio_init();
  adc_init();
  keyboard_init_keys();
  hid_init();
  // vTaskDelay(pdMS_TO_TICKS(1000));
  // gpio_reset_pin(GPIO_SELECT_0);
  // gpio_set_direction(GPIO_SELECT_0, GPIO_MODE_OUTPUT);
  // while (1) {
  //   gpio_set_level(GPIO_SELECT_0, 1);
  //   vTaskDelay(pdMS_TO_TICKS(100));
  // }

  while (1) {
    keyboard_task();
    hid_task();

    // for (uint8_t amux_channel = 0; amux_channel < AMUX_CHANNEL_COUNT; amux_channel++) {
    //   for (uint8_t i = 0; i < AMUX_SELECT_PINS_COUNT; i++) {
    //     gpio_set_level(amux_select_pins[i], (amux_channel >> i) & 1);
    //   }

    //   for (uint8_t adc_channel = 0; adc_channel < ADC_CHANNEL_COUNT; adc_channel++) {
    //     int raw_value = 0;
    //     adc_oneshot_read(adc_handle, adc_channels[adc_channel], &raw_value);
    //   }
    // }

    vTaskDelay(pdMS_TO_TICKS(10));
  }
}

void keyboard_select_adc(uint8_t _adc_channel) {
  adc_channel = _adc_channel;
}

void keyboard_select_amux(uint8_t amux_channel) {
  for (uint8_t i = 0; i < AMUX_SELECT_PINS_COUNT; i++) {
    gpio_set_level(amux_select_pins[i], (amux_channel >> i) & 1);
  }
}

uint16_t keyboard_read_adc() {
  int raw_value = 0;
  adc_oneshot_read(adc_handle, adc_channels[adc_channel], &raw_value);
  return raw_value;
}

void keyboard_close_adc() {
}

uint32_t keyboard_get_time() {
  return esp_timer_get_time();
}

void keyboard_read_config() {
  memcpy(&keyboard_user_config, &keyboard_default_user_config, sizeof(keyboard_user_config));
}

uint8_t keyboard_write_config(uint8_t *buffer, uint16_t offset, uint16_t size) {
  return 1;
}

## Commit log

2022-08-24 🎉 Abracadabra
    [Parametric_Key_Switch_Tester.stl, blank.scad, blank.stl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]
2022-08-25 🚧 Push input still not working, keyb recognized
2022-09-06 🔥 Remove firmware from repository
    [body.scad, cherry_void.scad, filler.scad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]
2022-09-10 🚧 Chamfered knob design
    [body.scad, filler.scad, knob.scad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]
2022-09-10 🚧 Playin with a design
    [body.scad, knob.scad, macrolev.scad]
2022-09-12 🚧 Trying NopSCADlib
    [body.scad, body.stl, bom.csv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]
2022-09-14 🚧 Stable outer shell
    [body.stl, bom.csv, knob.stl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]
2022-09-14 🚧 Bulkier design
    [main.scad]
2022-09-16 🚧 First proto
    [body.stl, body_base.stl, knob.stl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]
2022-09-22 🚚 Move back firmware, remove nopscadlib
    [Parametric_Key_Switch_Tester.stl, blank.stl, body.scad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]
2022-09-25 ♻️ New macrolev design, proto void switch
    [keycap.3mf, macrolev.scad, macrolev.stl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]
2022-09-27 🚧 POC adc sample working
    [keycap.3mf, levitator.3mf, macrolev.scad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]
2022-09-27 ✨ Switches working
2022-09-27 ✨ Keymap is now in config
2022-09-30 ♻️ Improve hall effect data processing
2022-10-12 ✨ Now working with key modifiers
2022-10-14 ⚗️ Trying kicad, prototype "plastic pcb"
    [macrolev.kicad_pcb, macrolev.kicad_sch, macrolev.scad]
2022-11-07 🚧 Pcb in progress
    [macrolev.kicad_pcb]
2023-01-17 📝 Add wooting 60HE pictures
    [macrolev.kicad_pcb, macrolev.kicad_sch]
2023-09-28 heyboard-layout-editor to scad and new kicad project
    [kicad_2.kicad_pcb, kicad_2.kicad_sch, kicad_2.step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]
2023-10-03 refactor readme file and remove old things
    [body.scad, filler.scad, keycap.3mf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]
2023-10-26 pcb rev1.0
    [kicad_2.kicad_pcb, kicad_2.kicad_sch, kicad_2.step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]
2023-10-27 doc(pcb): add pcb documentation
    [macrolev.kicad_pcb, macrolev.kicad_sch]
2023-10-31 fix(pcb): apply feedback from PrintedCircuitBoard sub
    [macrolev-old.kicad_pcb, macrolev.kicad_pcb, macrolev.kicad_sch]
2023-11-06 change pcb routing
    [macrolev.kicad_pcb, macrolev.kicad_sch]
2023-11-08 add caps on amux, change routing
    [macrolev-B_Cu.gbr, macrolev-B_Mask.gbr, macrolev-B_Paste.gbr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]
2023-11-22 feat: first stm32 firmware implem and test
    [macrolev.kicad_pcb]
2023-11-23 poc working, commiting before swapping usb library to tinyUSB (stm32MX one is meh)
    [macrolev.ioc, main.c]
2023-11-27 rework and nearly working
    [main.c]
2023-11-30 firmware working with cubeide framework
2023-12-24 fix: tap layer would never trigger
    [main.c]
2024-02-18 fix: fix hid descriptor for windows
    [main.c]
2024-03-04 wip: fix pcb
    [macrolev.kicad_pcb, macrolev.kicad_sch]
2024-05-12 fix: fix windows detection
    [main.c]
2024-06-16 wip rev 1.1
    [macrolev.kicad_pcb, macrolev.kicad_sch, utils.scad]
2024-09-12 wip: real time key logging
    [macrolev.kicad_pcb, macrolev.kicad_sch]
2024-10-20 wip: explore haptic feedback
    [macrolev.kicad_sch]
2024-11-11 fix: disable screaming mode, it blocked consumer keys
    [main.c]
2024-11-18 wip: starting new pcb Rev 2.0
    [layout_board.kicad_pcb, layout_board.kicad_sch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]
2024-11-20 wip: rev 2.0 pcb
    [layout_board.kicad_pcb, layout_board.kicad_sch]
2024-11-25 wip: working on flex cable
    [flex_connector.kicad_pcb, flex_connector.kicad_sch, layout_board.kicad_pcb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]
2024-11-25 wip: flex connector
    [flex_connector.kicad_pcb, flex_connector.kicad_sch, layout_board.kicad_pcb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]
2024-11-26 wip: add connector on layout board
    [layout_board.kicad_pcb]
2024-11-28 wip: remove flex pcb
    [flex_connector.kicad_pcb, flex_connector.kicad_sch, layout_board.kicad_pcb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]
2024-11-28 wip: add logo and qrcode
    [layout_board.kicad_pcb]
2024-11-30 wip: added logo
    [layout_board.kicad_pcb]
2024-12-01 wip: daughter board init
    [daughter_board.kicad_pcb, daughter_board.kicad_sch, layout_board.kicad_pcb]
2024-12-01 wip: daughter board done
    [daughter_board.kicad_pcb, daughter_board.kicad_sch, layout_board.kicad_pcb]
2024-12-01 wip: gerber files
    [daughter_board-B_Cu.gbr, daughter_board-B_Mask.gbr, daughter_board-B_Paste.gbr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]
2024-12-01 wip: changing amuxes
    [layout_board.kicad_pcb, layout_board.kicad_sch]
2024-12-03 release: Rev 2.0 sent to be manufactured
    [daughter_board-B_Cu.gbr, daughter_board-B_Mask.gbr, daughter_board-B_Silkscreen.gbr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]
2024-12-11 wip: esp32 firmware

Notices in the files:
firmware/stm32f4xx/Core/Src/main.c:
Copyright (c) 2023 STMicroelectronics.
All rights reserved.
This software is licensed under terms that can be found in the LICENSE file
